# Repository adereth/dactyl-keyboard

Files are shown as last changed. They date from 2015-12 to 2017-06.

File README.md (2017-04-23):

# The Dactyl Keyboard
The Dactyl is a parameterized, split-hand, concave, columnar, ergonomic keyboard.

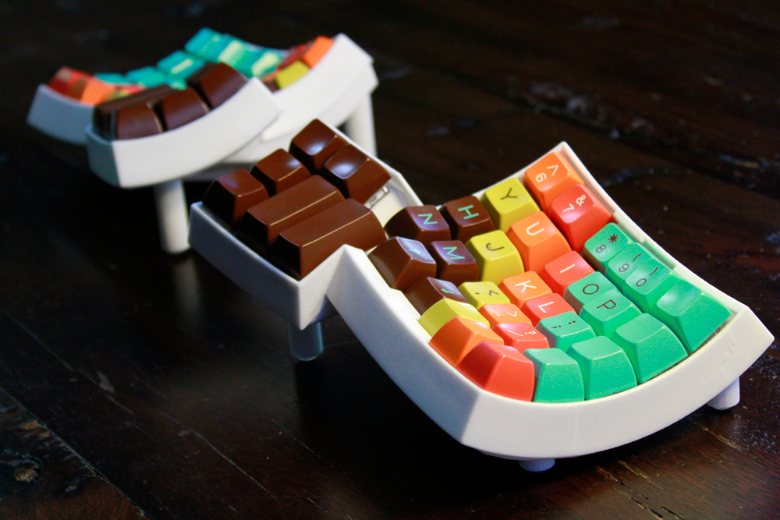
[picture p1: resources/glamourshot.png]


There's a talk about the motivation and design of the Dactyl that helps provide context for this repo:

IMAGE ALT TEXT HERE (https://www.youtube.com/watch?v=uk3A41U0iO4)

## Assembly

### Generating a Design

**Setting up the Clojure environment**
* [Install the Clojure runtime](https://clojure.org)
* [Install the Leiningen project manager](http://leiningen.org/)
* [Install OpenSCAD](http://www.openscad.org/)

**Generating the design**
* Run `lein repl`
* Load the file `(load-file "src/dactyl_keyboard/dactyl.clj")`
* This will regenerate the `things/*.scad` files
* Use OpenSCAD to open a `.scad` file.
* Make changes to design, repeat `load-file`, OpenSCAD will watch for changes and rerender.
* When done, use OpenSCAD to export STL files

**Tips**
* [Some other ways to evaluate the clojure design file](http://stackoverflow.com/a/28213489)
* [Example designing with clojure](http://adereth.github.io/blog/2014/04/09/3d-printing-with-clojure/)

### Printing
Pregenerated STL files are available in the [things/](things/) directory.

### Wiring
Masks for the flexible PCBs I used are available for the [left](resources/pcb-left.svg) and [right](resources/pcb-right.svg) side.

A [very rough guide for the brave is here](guide/README.org#wiring) - It will be improved over time (**TODO**)!

## License

Copyright © 2015 Matthew Adereth

The source code for generating the models (everything excluding the [things/](things/) and [resources/](resources/) directories is distributed under the [GNU AFFERO GENERAL PUBLIC LICENSE Version 3](LICENSE).  The generated models and PCB designs are distributed under the [Creative Commons Attribution-ShareAlike License Version 4.0](LICENSE-models).

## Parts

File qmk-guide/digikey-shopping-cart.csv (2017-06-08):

Index | Quantity | Part Number | Description | Customer Reference | Available Quantity | Backorder Quantity | Unit Price USD | Extended Price USD
1 | 2 | CP-43514-ND | CONN JACK 4COND 3.5MM R/A |  | 2 | 0 | 1.06000 | 2.12
2 | 2 | 2.2KQBK-ND | RES 2.2K OHM 1/4W 5% AXIAL |  | 2 | 0 | 0.10000 | 0.20
3 | 3 | 220QBK-ND | RES 220 OHM 1/4W 5% AXIAL |  | 3 | 0 | 0.10000 | 0.30
4 | 1 | 1528-1993-ND | TEENSY (ATMEGA32U4 USB DEV BOARD |  | 1 | 0 | 19.94000 | 19.94
5 | 100 | 1N4148FS-ND | DIODE GEN PURP 100V 200MA DO35 |  | 100 | 0 | 0.03080 | 3.08
6 | 10 | ED3050-5-ND | CONN IC DIP SOCKET 28POS TIN |  | 10 | 0 | 0.31500 | 3.15
7 | 1 | MCP23018-E/SP-ND | IC I/O EXPANDER I2C 16B 28SDIP |  | 1 | 0 | 1.56000 | 1.56

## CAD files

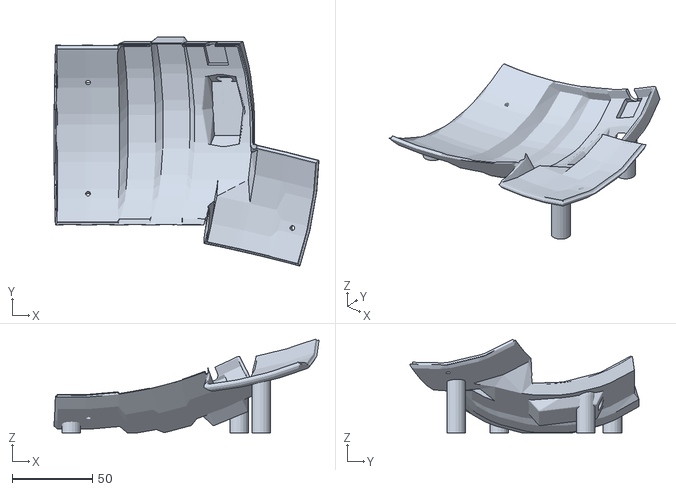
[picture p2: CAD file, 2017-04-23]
things/dactyl-bottom-left-with-teensy.stl
164.7 x 142.2 x 58.3

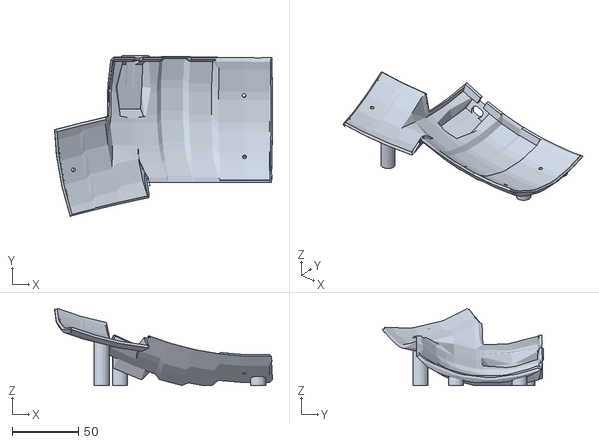
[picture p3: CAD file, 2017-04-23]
things/lightcycle-cherry-bottom-right.stl
164.7 x 121.4 x 58.4

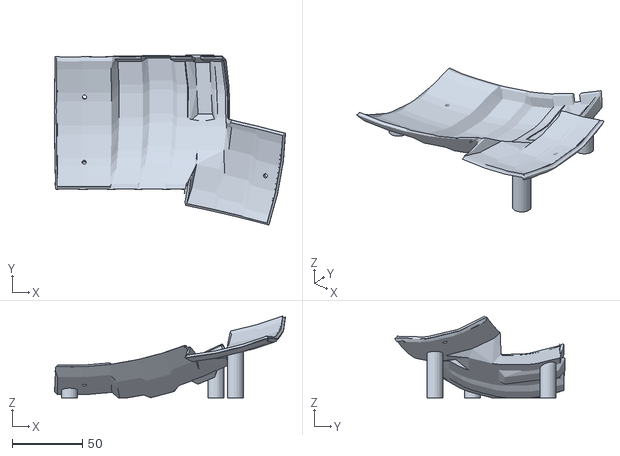
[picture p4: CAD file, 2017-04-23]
things/lightcycle-cherry-bottom-left.stl
164.7 x 121.4 x 58.4

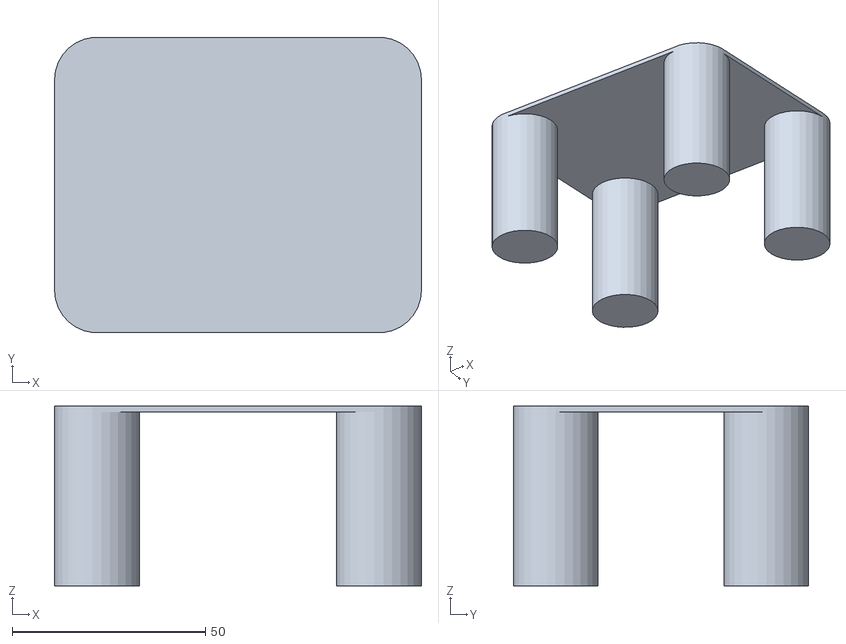
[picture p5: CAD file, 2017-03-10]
things/wrist.stl
95.0 x 76.4 x 46.5

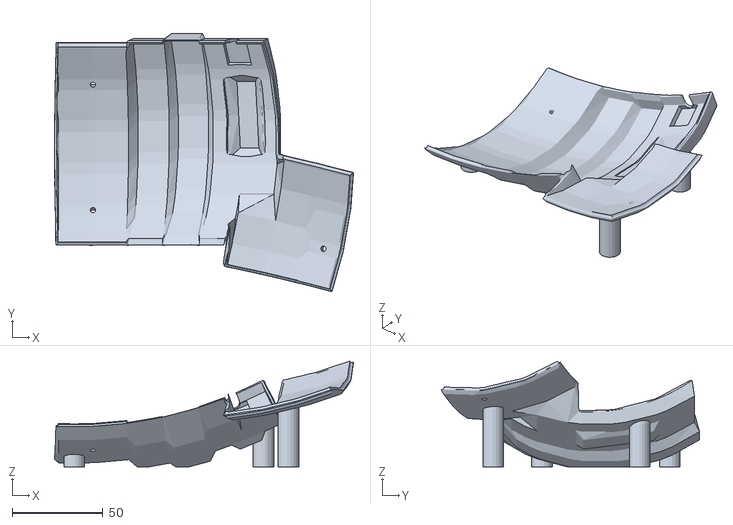
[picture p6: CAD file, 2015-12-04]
things/dactyl-bottom-left.stl
164.7 x 142.2 x 58.3

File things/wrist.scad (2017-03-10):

union () {
  hull () {
    translate ([73/2, 27.25, 45.75]) {
      cylinder (h=1.5, r=11, center=true);
    }
    mirror ([-1, 0, 0]) {
      translate ([73/2, 27.25, 45.75]) {
        cylinder (h=1.5, r=11, center=true);
      }
    }
    mirror ([0, -1, 0]) {
      translate ([73/2, 27.25, 45.75]) {
        cylinder (h=1.5, r=11, center=true);
      }
    }
    mirror ([-1, 0, 0]) {
      mirror ([0, -1, 0]) {
        translate ([73/2, 27.25, 45.75]) {
          cylinder (h=1.5, r=11, center=true);
        }
      }
    }
  }
  hull () {
    translate ([73/2, 27.25, 45.75]) {
      cylinder (h=1.5, r=11, center=true);
    }
    translate ([0, 0, 1/2]) {
      linear_extrude (height=1, twist=0.0, convexity=0, center=true){
        projection (cut = false) {
          translate ([73/2, 27.25, 45.75]) {
            cylinder (h=1.5, r=11, center=true);
          }
        }
      }
    }
  }
  hull () {
    mirror ([-1, 0, 0]) {
      translate ([73/2, 27.25, 45.75]) {
        cylinder (h=1.5, r=11, center=true);
      }
    }
    translate ([0, 0, 1/2]) {
      linear_extrude (height=1, twist=0.0, convexity=0, center=true){
        projection (cut = false) {
          mirror ([-1, 0, 0]) {
            translate ([73/2, 27.25, 45.75]) {
              cylinder (h=1.5, r=11, center=true);
            }
          }
        }
      }
    }
  }
  hull () {
    mirror ([0, -1, 0]) {
      translate ([73/2, 27.25, 45.75]) {
        cylinder (h=1.5, r=11, center=true);
      }
    }
    translate ([0, 0, 1/2]) {
      linear_extrude (height=1, twist=0.0, convexity=0, center=true){
        projection (cut = false) {
          mirror ([0, -1, 0]) {
            translate ([73/2, 27.25, 45.75]) {
              cylinder (h=1.5, r=11, center=true);
            }
          }
        }
      }
    }
  }
  hull () {
    mirror ([-1, 0, 0]) {
      mirror ([0, -1, 0]) {
        translate ([73/2, 27.25, 45.75]) {
          cylinder (h=1.5, r=11, center=true);
        }
      }
    }
    translate ([0, 0, 1/2]) {
      linear_extrude (height=1, twist=0.0, convexity=0, center=true){
        projection (cut = false) {
          mirror ([-1, 0, 0]) {
            mirror ([0, -1, 0]) {
              translate ([73/2, 27.25, 45.75]) {
                cylinder (h=1.5, r=11, center=true);
              }
            }
          }
        }
      }
    }
  }
}

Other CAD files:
things/dactyl-bottom-right.stl

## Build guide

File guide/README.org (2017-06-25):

* Preparation and Cost
  Get all the parts / raw material:
  - For the 3D printing there are two options:
    1. Filament, which is the basis for 3D printing. Luckily I could print at my work-place
       which reduced the cost from 210€ to 70€. The kind of filament you need depends on the 3D
       printer you have available.
    2. Buy the printout of adareth's model at shapeways for 210€ over here
       http://www.shapeways.com/designer/adereth/creations
  - Decide on the switches
    - If you are going to invest a whole lot of time and money for a custom keyboard instead of
      buying one for 10€ I'd recommend to use your favorite switch-type. To make a
      well-informed decision I bought a switch-tester for this from massdrop and decided on
      Cherry MX Whites. https://www.massdrop.com/buy/varmilo-switch-tester-with-anodized-case
    - I ordered 70 Cherry MX Whites from here:
      https://mechanicalkeyboards.com/shop/index.php?l=product_detail&p=847
  - Decide on the key caps
    - On the glamour shot you can see the 1976 keycap set; it used to be sold over here:
      http://pimpmykeyboard.com/sa-1976-keycap-set/ but the link is dead right now. You could
      try this link: https://www.massdrop.com/buy/nineteenseventysix-sa-keycap-set but it is a
      massdrop which is way different from usual online-stores. If you find a site that sells
      these, make sure you get the right amount and type of keys according to the layout.
    - I got the "TKL Base Set + TKL Modifier" from over here:
      http://pimpmykeyboard.com/dsa-pbt-abs-blank-keycap-sets/ but I'm still two long keys
      short, I will have to order those specifically and I have a bunch of keys I don't use
      left-over.
  - The USB-Cable that connects the keyboard to your computer
    - It's an USB 2.0 to USB Mini-B cable, make sure you get one that is 2 meters long, it
      really makes handling the keyboard so much more comfortable
    - https://www.amazon.de/gp/product/B00NH11N5A/
  - The main controller (right half)
    - A Teensy 2.0, I got that one from here: https://www.pjrc.com/store/teensy.html
  - The chip, connectors and cable to give life to the left half
    - TRRS cable and jacks
      - Got my TRRS cable from here: http://www.digikey.de/product-search/de?keywords=839-1257-ND
      - Got my TRRS jacks from here: http://www.digikey.de/product-search/de?keywords=CP-43514-ND
    - MCP23018 16 bit IO Expander
      - Got mine from here: http://www.digikey.de/product-search/de?keywords=MCP23018-E%2FSP-ND

  What I spend on my keyboard (should give you a rough estimate for your build):
  | item                              | cost |
  |-----------------------------------+------|
  | filament                          |   70 |
  | switch-tester                     |   30 |
  | key-caps                          |   70 |
  | teensy 2.0                        |   30 |
  | switches                          |   60 |
  | usb cable                         |   10 |
  | IO Expander, TRRS jacks and cable |   30 |
  |-----------------------------------+------|
  | overall cost                      |  300 |
  #+TBLFM: @9$2=vsum(@2$2..@8$2)

  My choices / advantages:
  - Using the soldering iron at the uni-workshop for free
  - 76 Diodes for free
  - Soldering wire and copper for free
  - All the resistors used for free (5 resistors are used)
  - Several files for working out the rough edges of the 3D-printout

  Depending on what you have available you might spend more or less money than me; however, 300€
  is a good rough estimate.

  After all the parts have arrived it is safe to move on to the next section.

* Wiring
  It is assumed that you have printed the casing successfully.

  1) Plug the switches into the casing. No glue is needed; the casing provides the perfect fit.
  2) Put the keycaps on the switches
     - Note that in the pictures here some of the long keys on the thumb-part are too short;
       that's why it doesn't look symmetrical

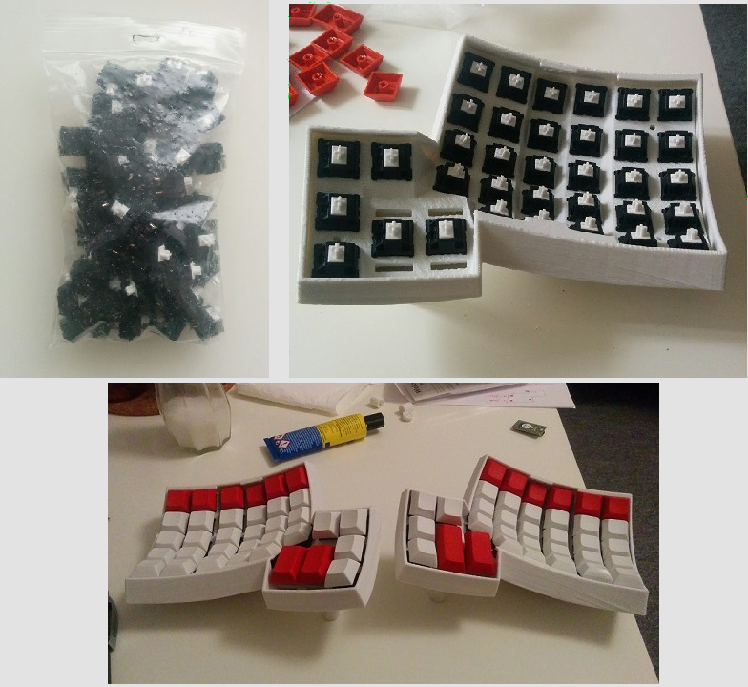
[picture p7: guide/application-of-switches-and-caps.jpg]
  

  Now going further on in the guide there are two options
  1. The first option is to print flexible PCBs. The advantage is that you save a lot of wiring
     business, everything looks rather clean and you don't have to worry about your cables being too
     thick such that the casing doesn't close. However, if you don't have the means to print out such
     PCBs there is the second option, wiring everything by hand.
     - The guide for this PCB-option is very rough indeed and it doesn't include the firmware
       used. Wiring and firmware play extremely close together--wiring before knowing your
       firmware is like buying a shoe without measuring your feet before. For this option,
       information about the exact firmware is not published, this in addition to the fact that
       the pictures in this rough guide are incomplete makes this option extremely
       beginner-unfriendly. Going in blind-sided like this may lead to one of these things:
       1. reprogramming huge parts of the firmware to match your wiring, which comes with a ton of
          debugging.
       2. rewiring to adapt to what the firmware expects, which may easily double your work here.
     - [[Route 1: Dactyl Flexible PCB Rough Guide]]
  2. The second option is to hand-wire everything. For people like me, who had never soldered before,
     this was great pain and pleasure.
     - Here too firmware and wiring go hand in hand, you pretty much have to have a detailed look
       at the firmware you are using before wiring anything. I provide my modification of the
       "ergodox-firmware" over here: https://github.com/BubblesToTheLimit/ergodox-firmware
       - TODO: Make a successfull pull-request, such that it is available in the official
         ergodox-firmware
     - Some of the steps of this guide may not be described in much detail, but in contrast to
       option one there is a whole lot more information.
     - [[Route 2: Dactyl Hand-Wiring Guide]]

** Route 1: Dactyl Flexible PCB Rough Guide
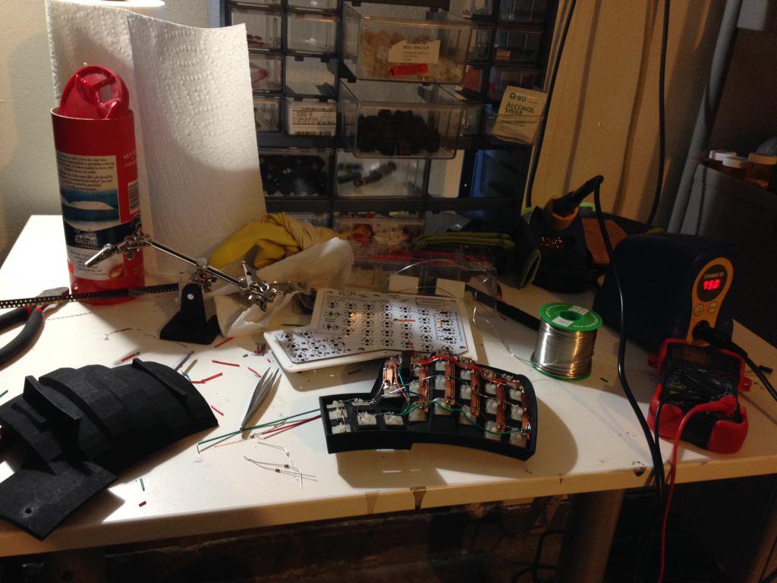
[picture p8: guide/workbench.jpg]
   

   For now, take a look at the images and try to figure things out; I know that's not great (it's
   better than nothing!)

*** Making the PCB
    Get two sheets of 6in square Pyralux™. Use the Toner Transfer method to etch the Pyralux sheets as
    you would a usual PCB

    #+BEGIN_QUOTE
    NOTE: If you only have an Inkjet make photocopies of the print out. Voilà, Toner based copies!
    #+END_QUOTE

    [[http://www.instructables.com/id/Toner-transfer-no-soak-high-quality-double-sided/][Here's a handy toner transfer guide ...]]

    Print these PCB designs out...

    Left hand:

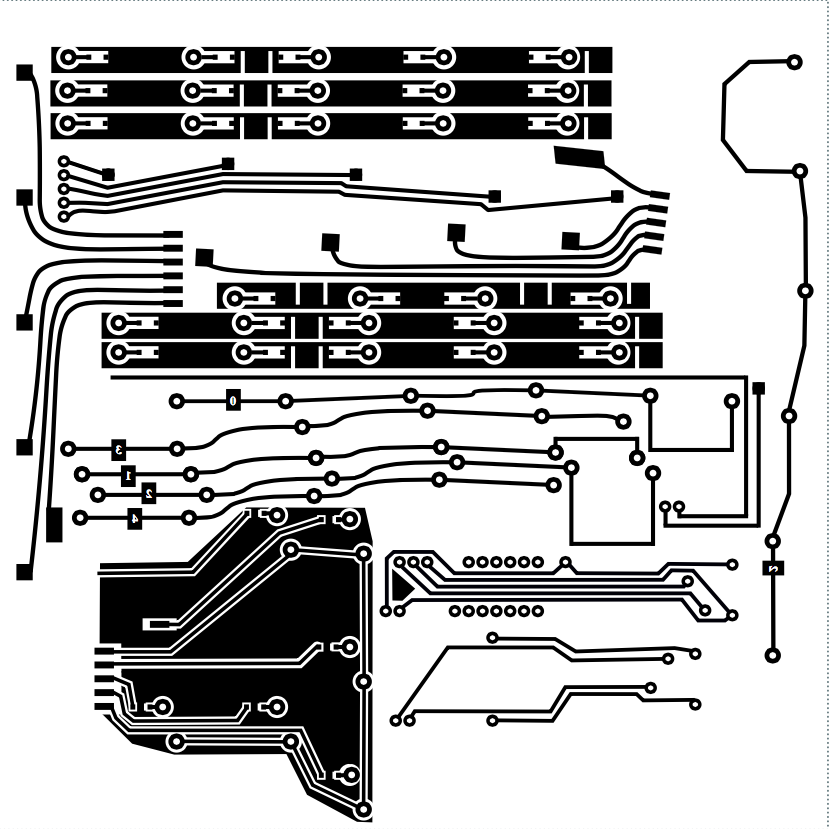
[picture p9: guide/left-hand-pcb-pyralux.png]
    

    Right hand:

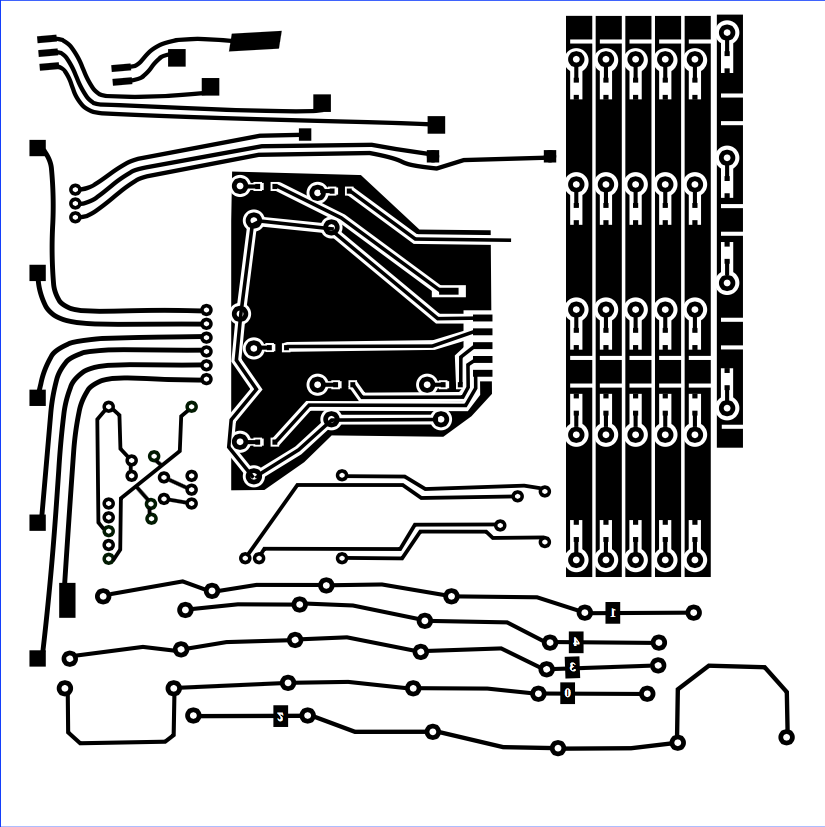
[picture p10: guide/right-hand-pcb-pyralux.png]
    

    When you're done etching, you'll need to carefully cut the pcb into pieces... See the images
    below.

*** Applying the PCB to the electronical parts
    The thumb cluster pcb for the left hand:

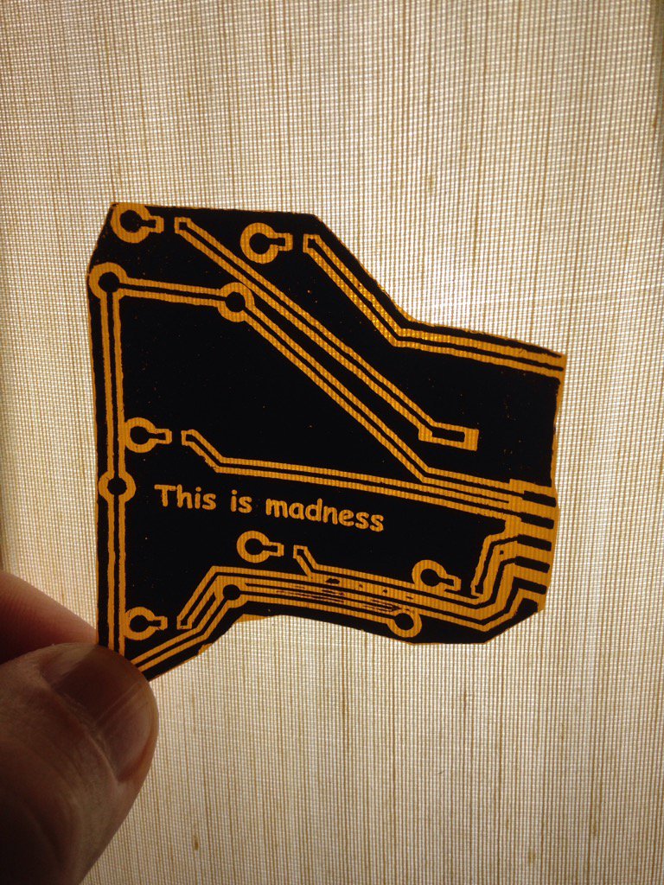
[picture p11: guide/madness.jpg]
    

    Solder the MCP like so:

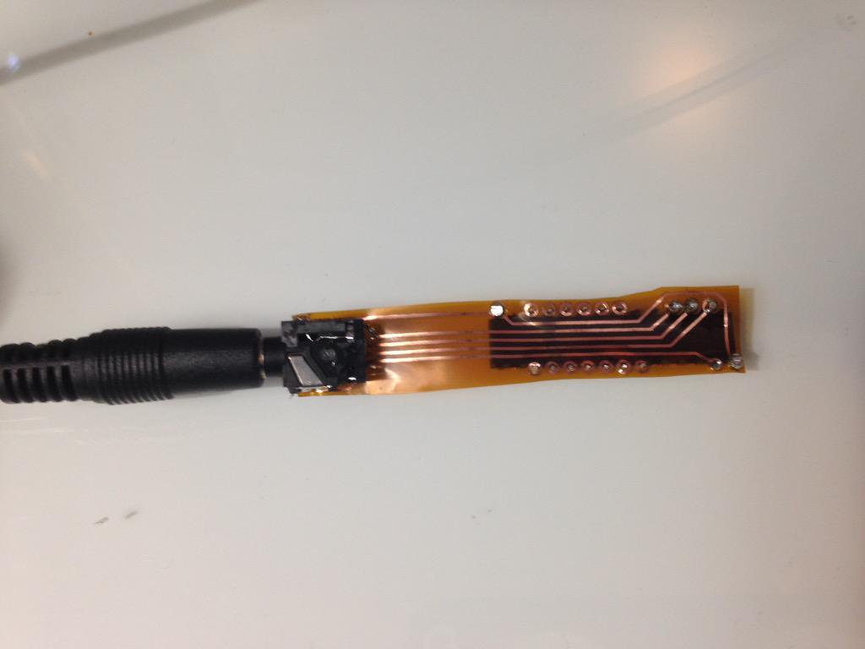
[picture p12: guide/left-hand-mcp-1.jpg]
    
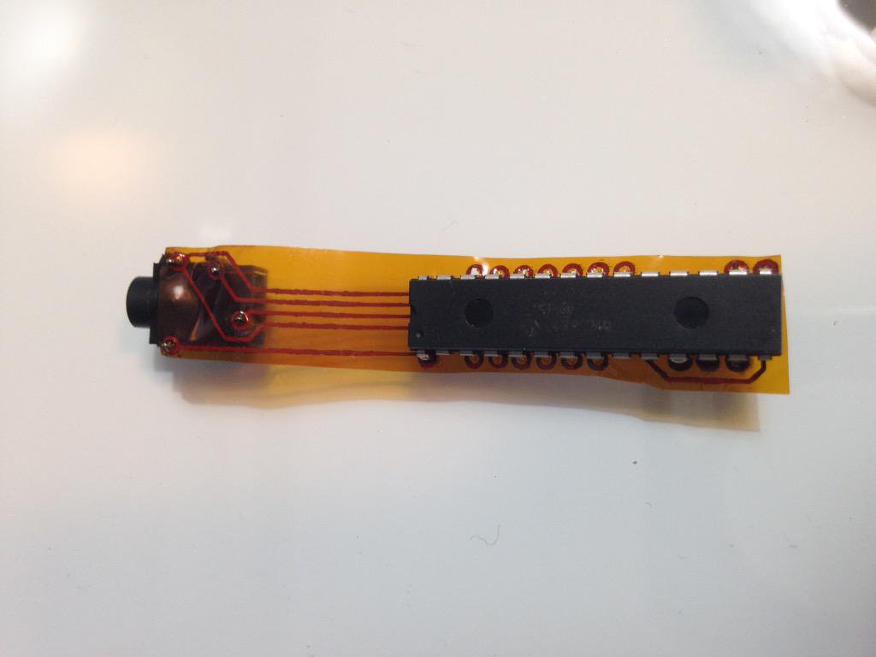
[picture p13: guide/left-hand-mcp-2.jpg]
    

    Solder the Teensy 2.0 like so:

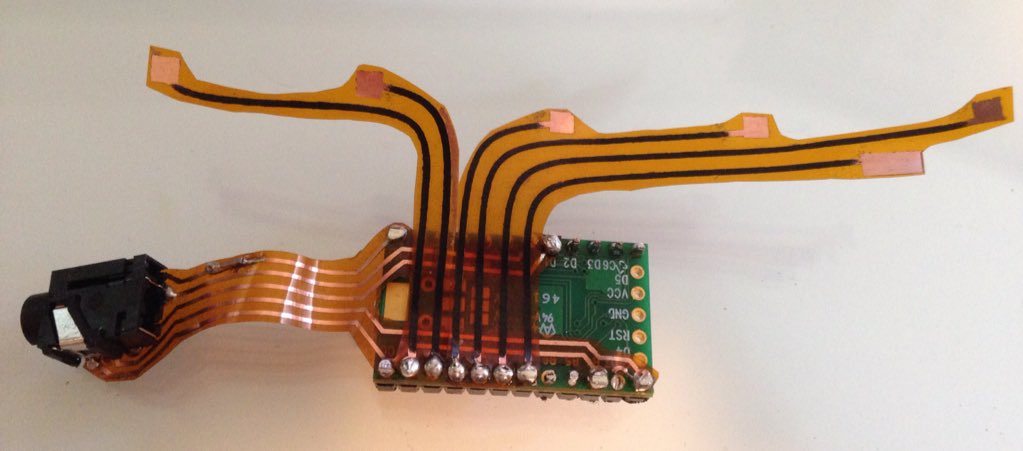
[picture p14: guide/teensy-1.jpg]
    

    The two 2.2kΩ (Red Red Red Gold) pull-up resistors ensure a clear signal between the USB controller and the I/O expander.
    [[https://learn.sparkfun.com/tutorials/pull-up-resistors][Read more about pull-up resistors here]].

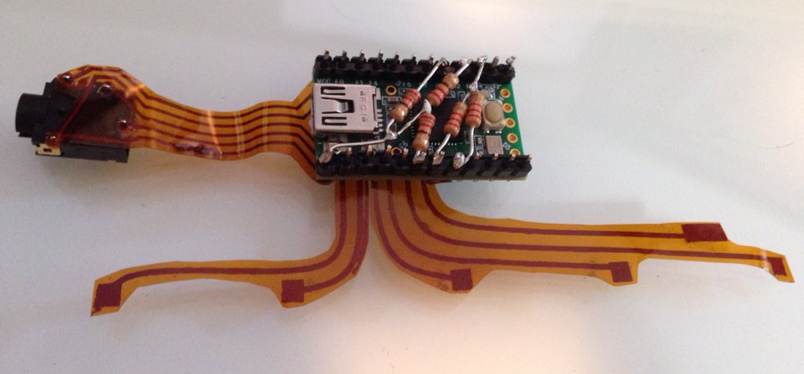
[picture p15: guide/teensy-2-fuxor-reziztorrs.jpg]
    

    Each hand of the keyboard will wire up like so:

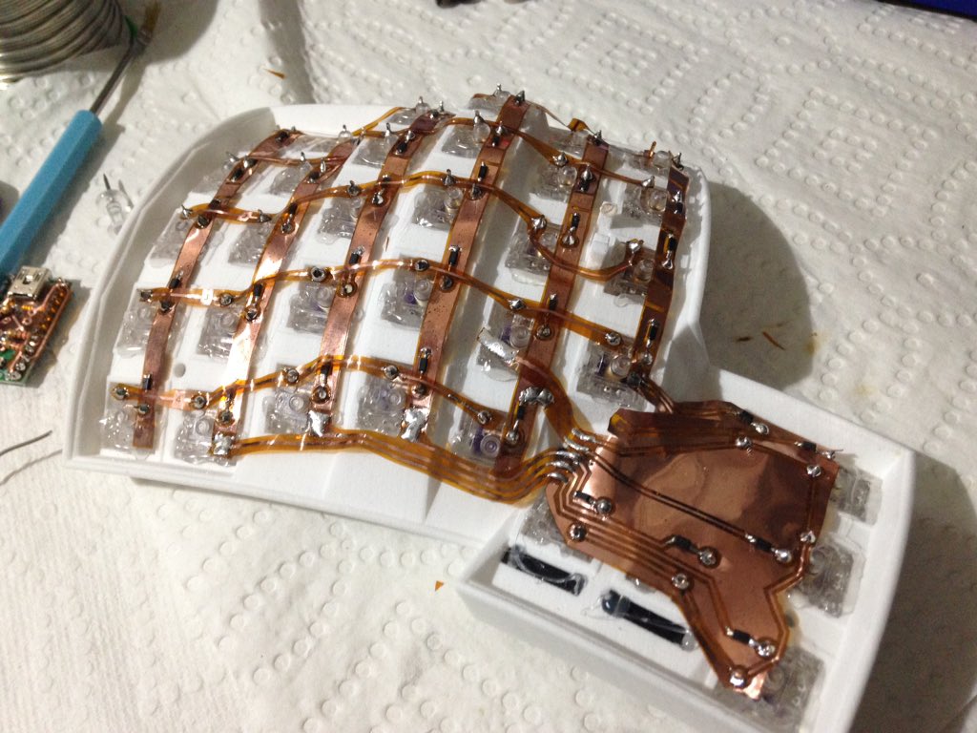
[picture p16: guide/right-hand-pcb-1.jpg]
    

    Teensy goes here... note the rows soldered to the teensy via the Pyralux:

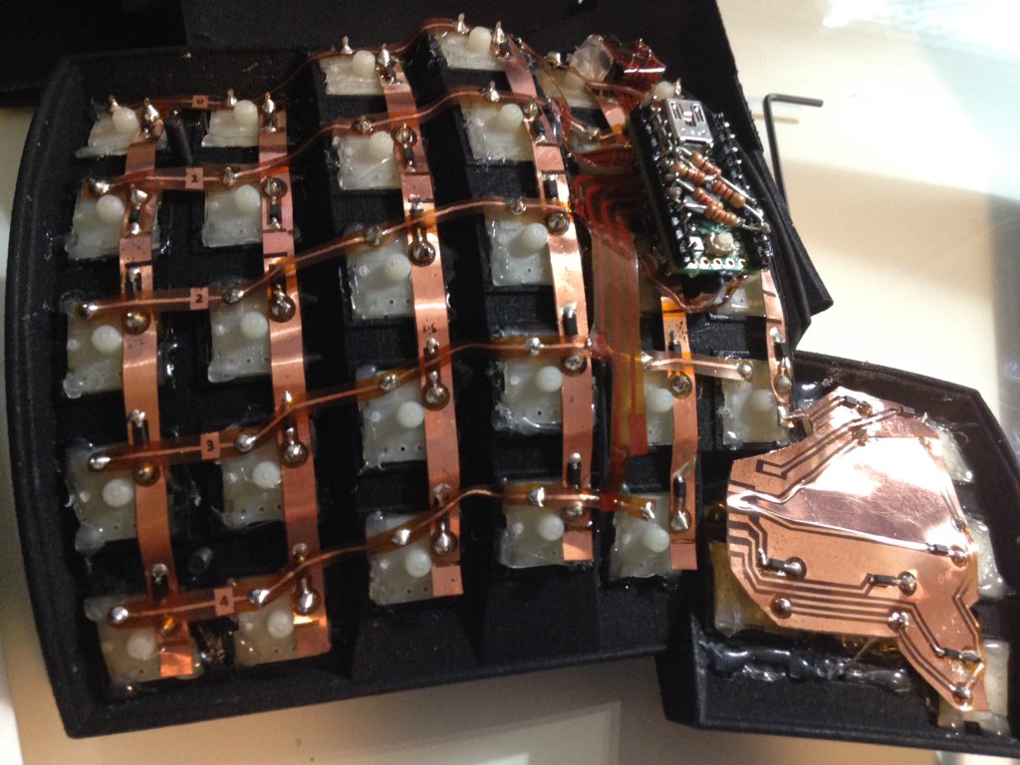
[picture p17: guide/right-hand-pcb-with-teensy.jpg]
    

    Here the left hand:

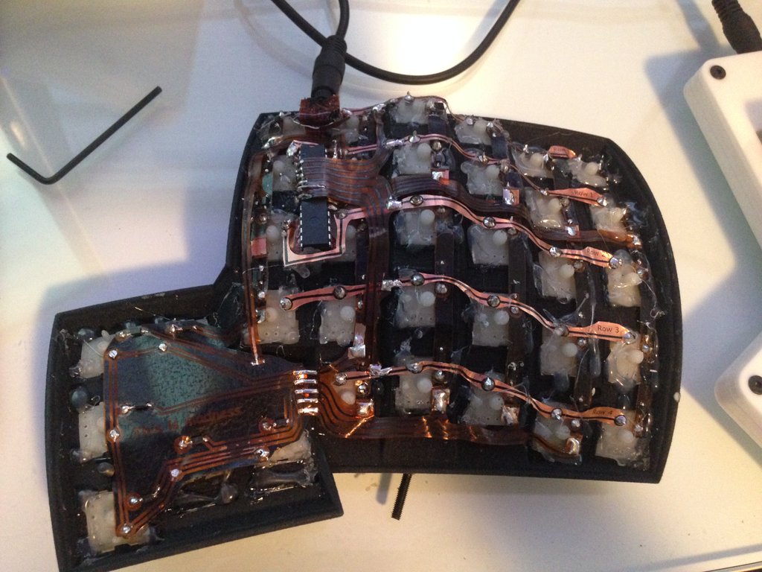
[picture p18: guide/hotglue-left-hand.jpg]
    

** Route 2: Dactyl Hand-Wiring Guide
*** Step 1: Creating the rows
    Using the copper wire you solder each row together, notice how the thumb-part gets its own
    row. If you take a close look you can see how I did do a messy job soldering, I had to redo
    some of the parts because they weren't soldered properly. Do this for both sides. It doesn't
    matter which of the two available pins of each switch you chose for the row, but for it to
    look clean you should decide for either one of them.

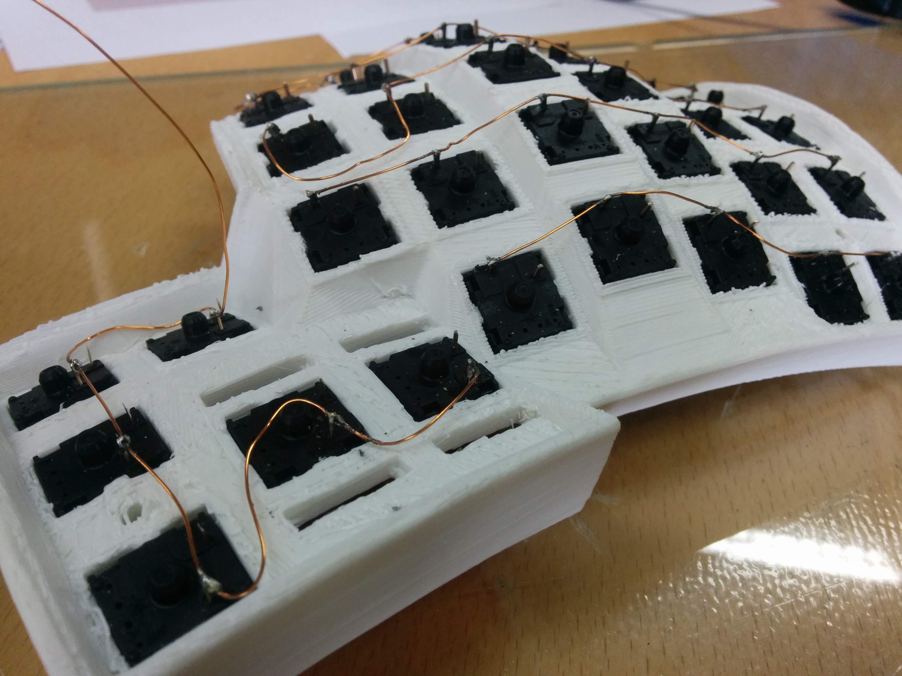
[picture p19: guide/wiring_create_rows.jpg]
    

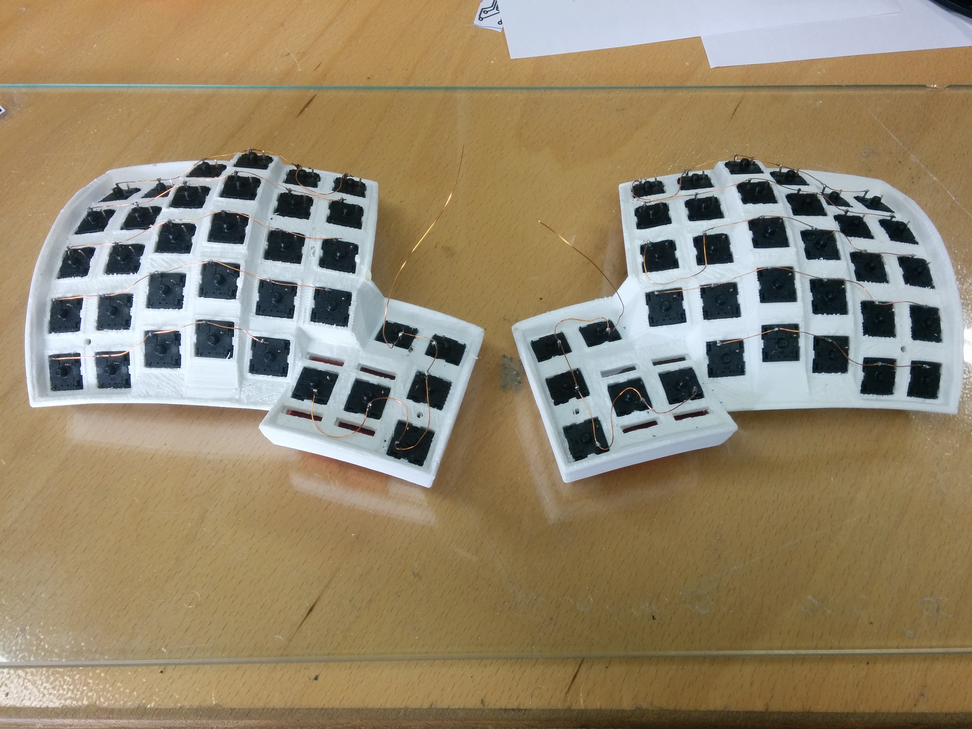
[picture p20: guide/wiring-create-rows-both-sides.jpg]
    

    You might want to go ahead and test each one of the 70 switches with a multimeter.

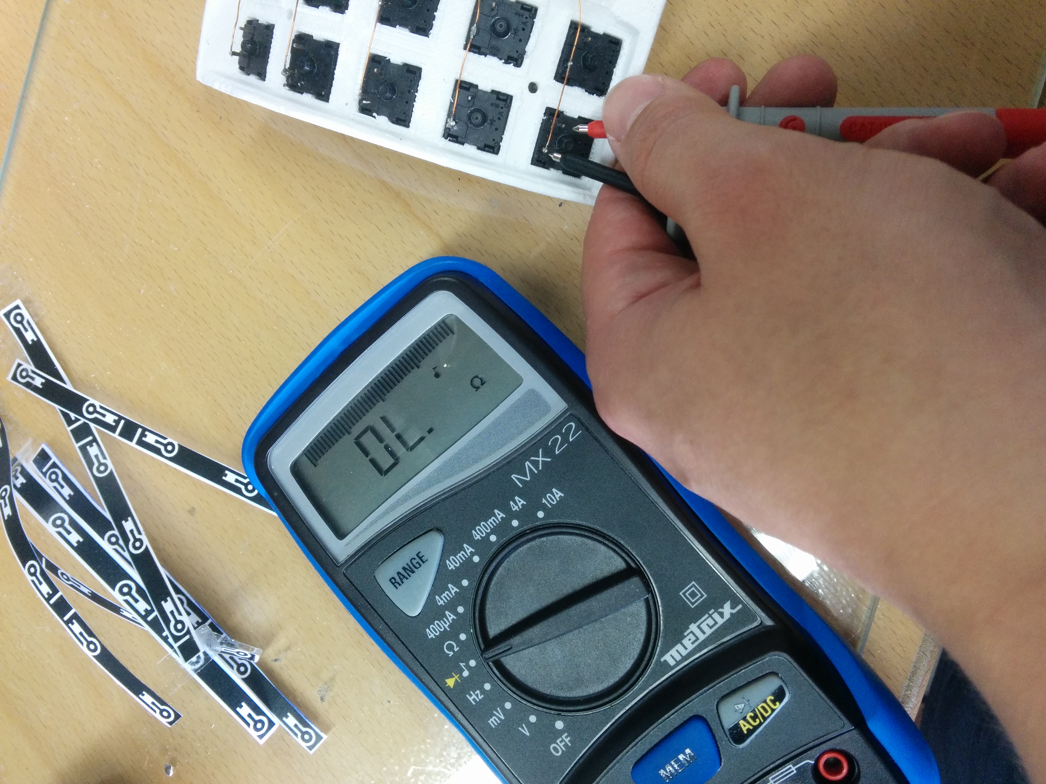
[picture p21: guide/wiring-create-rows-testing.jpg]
    

*** Step 2: Create the columns
    The next step is to create the columns by soldering the diodes. There are two options for
    soldering the diodes, all heading towards the switch or all heading away from the
    switch. These two ways are called "row-driven" or "column-driven" and here again it is
    cruciual for the firmware and the actual wiring to be on the same page.

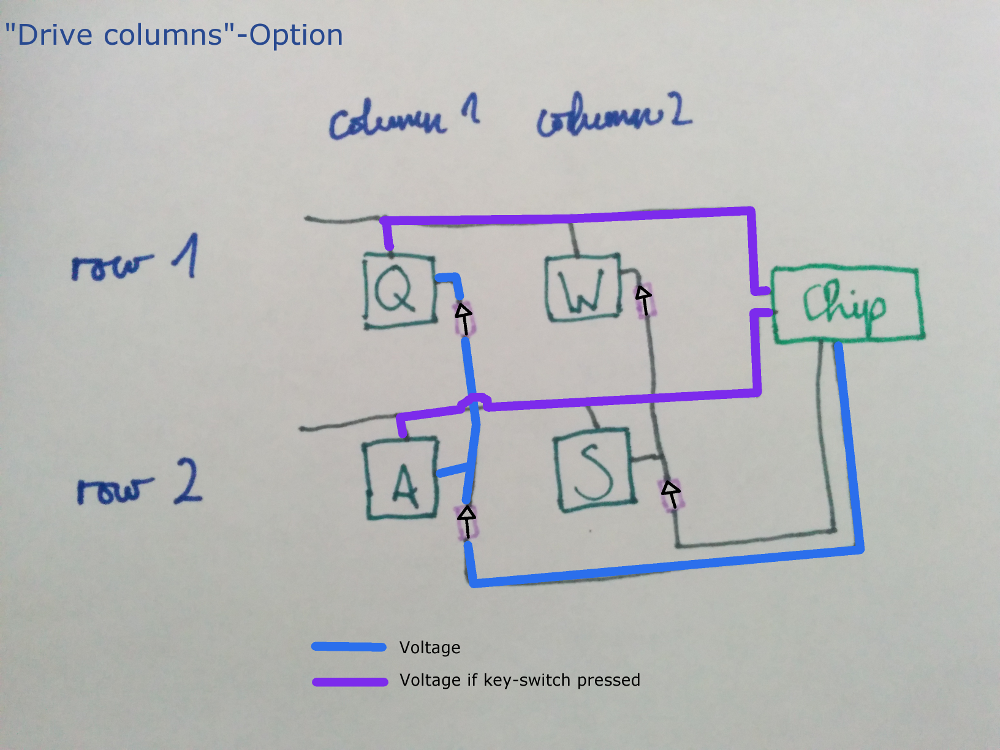
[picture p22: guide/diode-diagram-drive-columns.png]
    

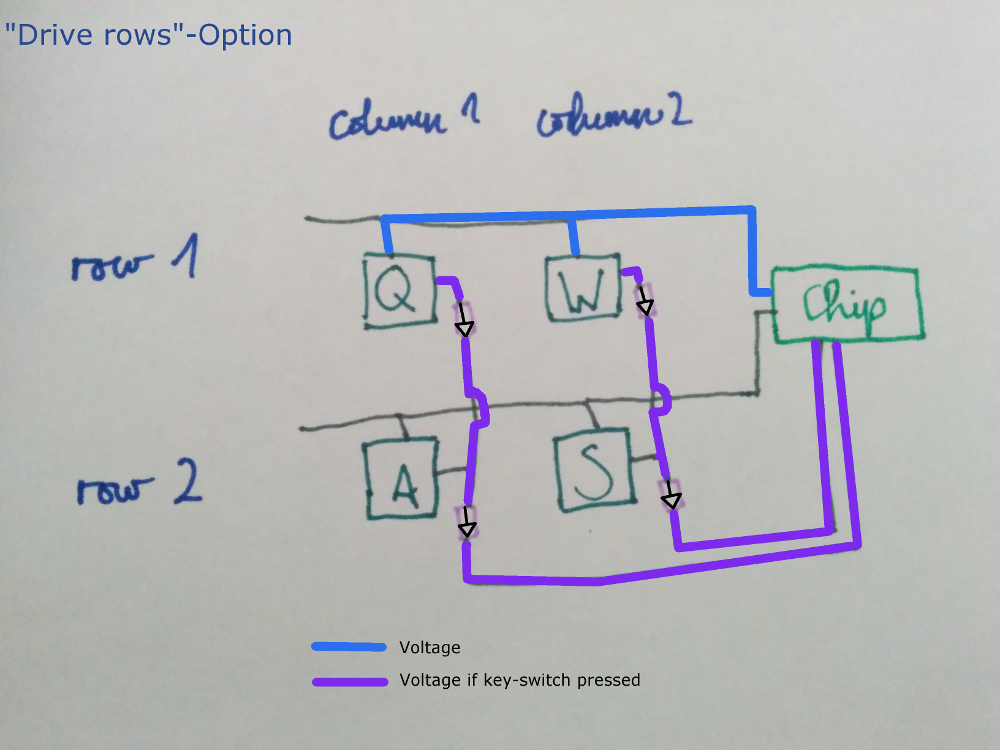
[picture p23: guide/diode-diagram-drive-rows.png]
    

    If you want to try and use the "tmk_keyboard" firmware which seems to be also interesting you
    want to wire the diodes in the according way (check whether the tmk_keyboard firmware expects
    a row-driven or a column-driven setup).

    As you can see in these following pictures, I went for the "row-driven" setup (visible by the
    direction of the diodes, the black line being towards the key-switches). This first picture
    doesn't show how the 6 thumb-keys are actually individually connected to the 6 main columns,
    but note the small black line on each diode.

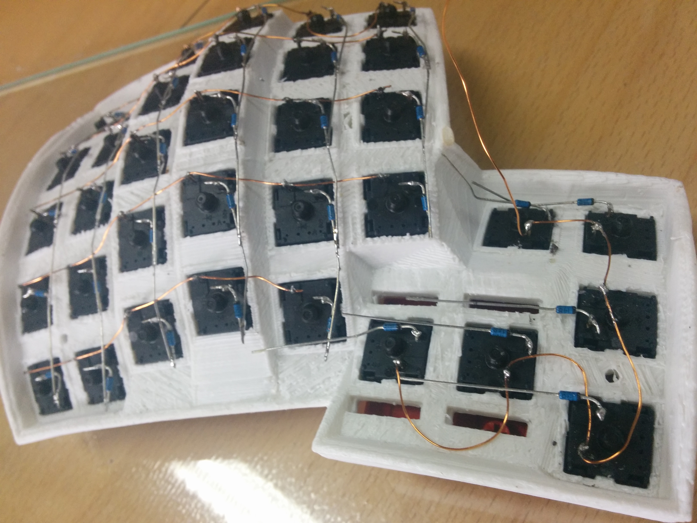
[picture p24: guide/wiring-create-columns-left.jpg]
    

    This second picture shows how the 6 thumb-keys are actually connected to the 6 main columns.

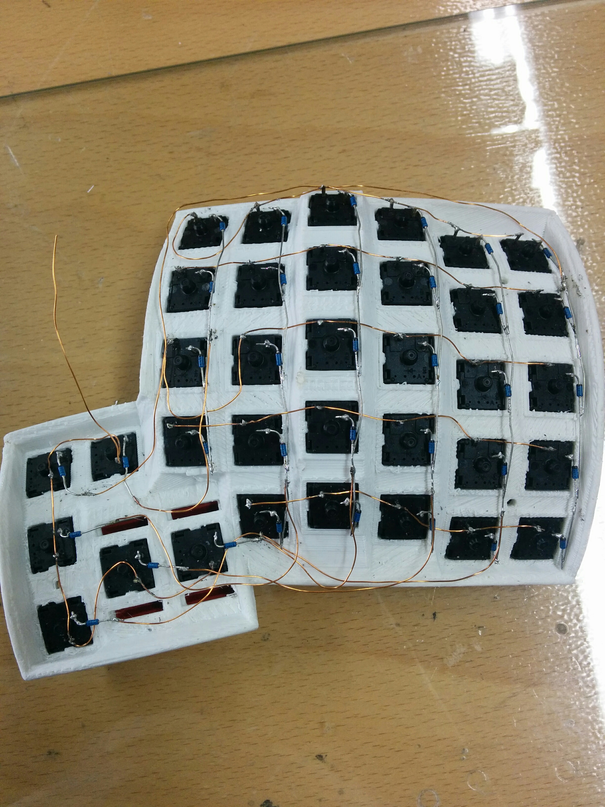
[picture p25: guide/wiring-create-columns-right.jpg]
    

    How thumb-keys are wired again depends on the firmware. The following picture shows the wiring
    of the thumb keys more clearly and also the part in the code that reflects this wiring
    (ergodox-firmware/src/keyboard/dactyl/matrix.h).

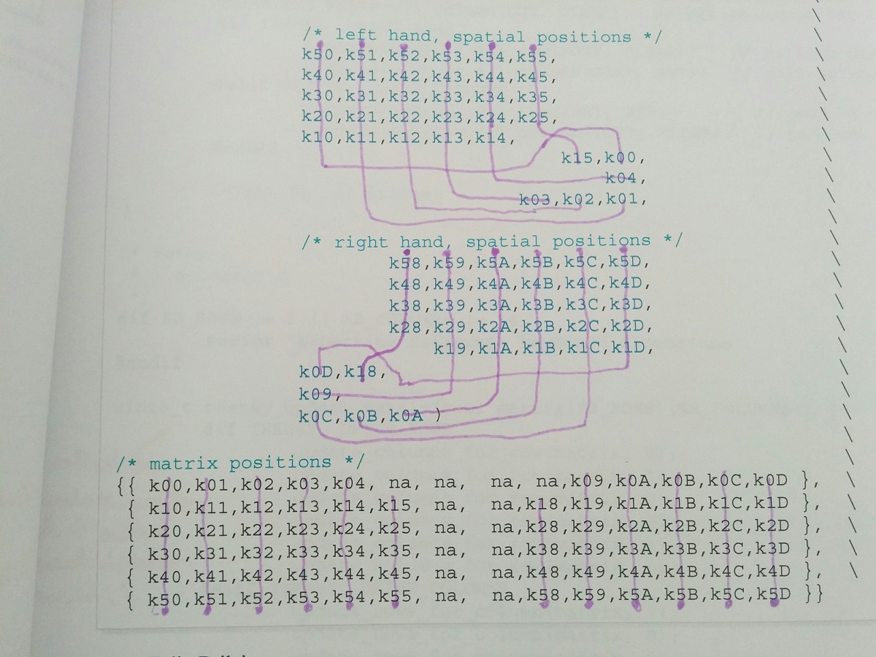
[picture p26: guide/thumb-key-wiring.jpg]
    

*** Step 3: Put the Teensy and the MCP in place
    This next step is to wire the Teensy 2.0 and the MCP 23018 in place.
    Everything necessary for that really is the following circuit diagram.

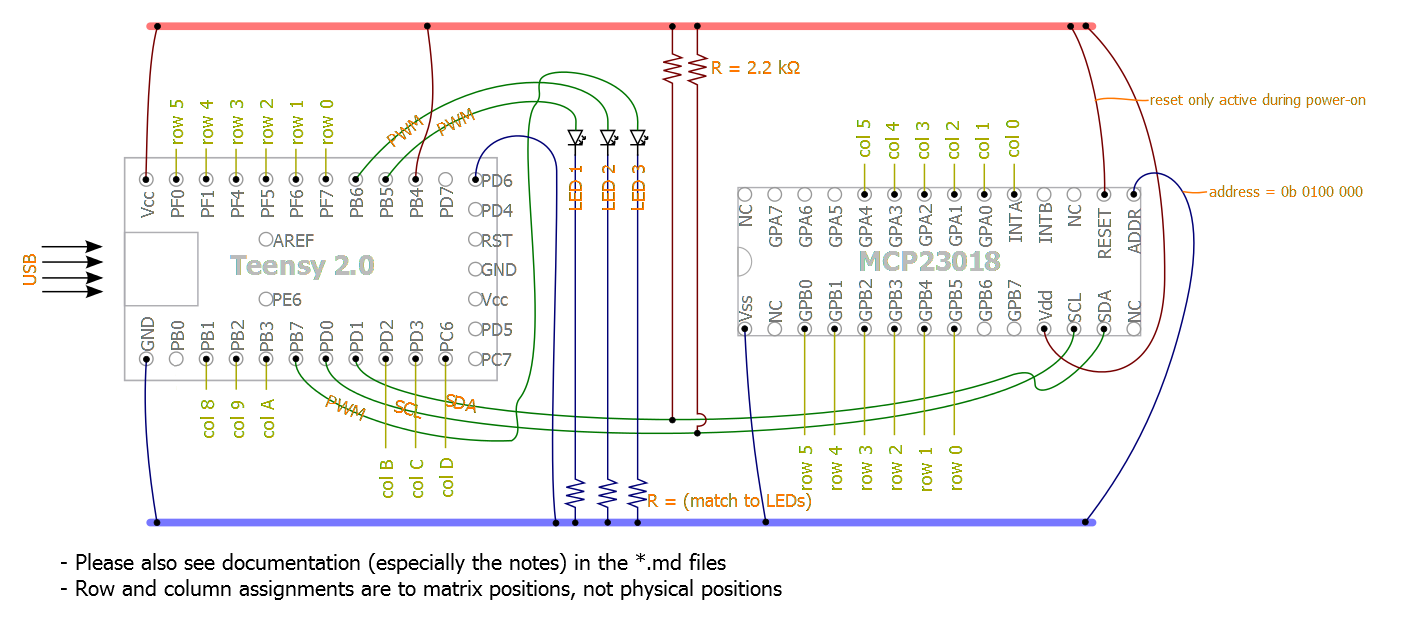
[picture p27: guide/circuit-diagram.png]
    

    Things to note here:
    - The columns for the MCP go from 0 to 6, the columns for the Teensy go from 7 to D (counting
      in hexadecimal) which makes great sense, since the MCP is to the left of the Teensy and we
      read from left to right.
    - When debugging this and using the ergodox-firmware, both sides have to be wired completely
      and actually with the TRRS connected. Don't expect the keyboard to work before that. The
      reason is that the ergodox-firmware stops completely if either the Teensy or the MCP weren't
      initiated properly.
    - The LEDs are handy for debugging; definitely go ahead and connect those. When the keyboard
      starts successfully two of the LEDs light up shortly.
    - From the Teensy over to the MCP go exactly 4 connections. The blue, the red and the two green
      ones. This is done using the TRRS jacks and cable.
    - Yes, the connection from B4 to VCC doesn't seem to make any sense, but the B4 port actually
      gets used directly in the ergodox-firmware, so just connect those connections that make no
      sense on first sight and either don't question it or find out why this is necessary by going
      through the firmware in great detail.

    This is how the trrs jacks are wired:

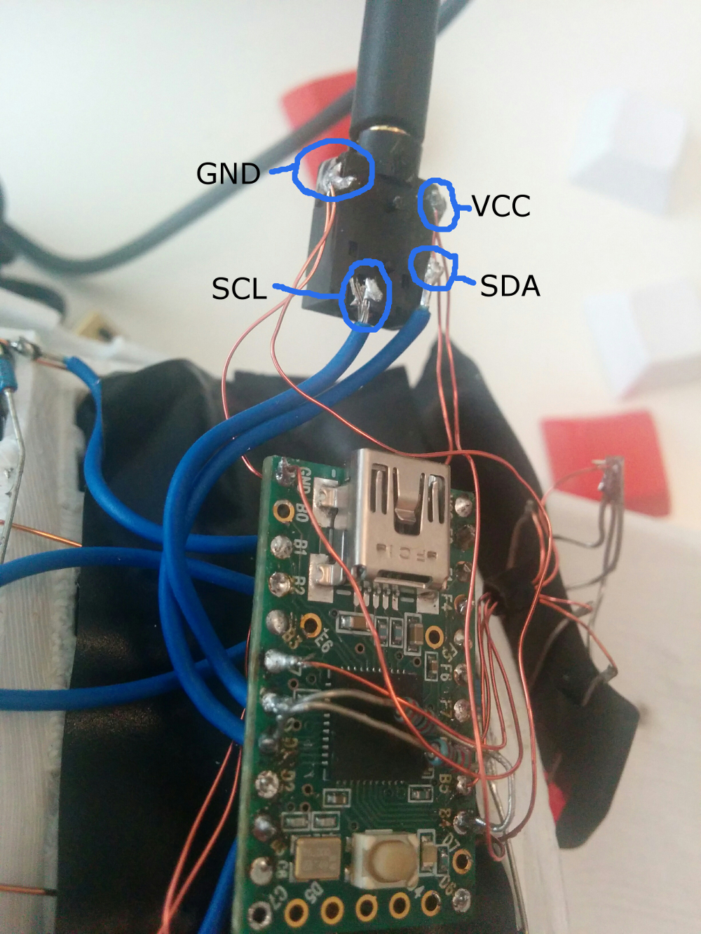
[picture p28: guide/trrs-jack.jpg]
    

    After you are done you might have the following result:

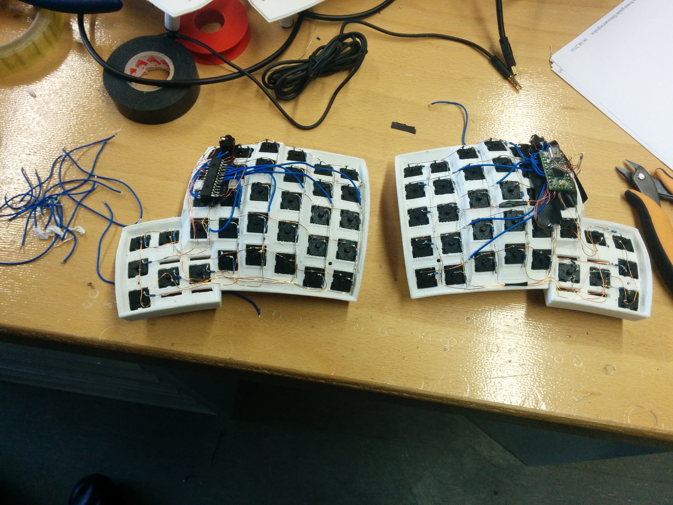
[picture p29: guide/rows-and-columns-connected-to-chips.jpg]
    

    Good luck!

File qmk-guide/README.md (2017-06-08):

# The EZ Way to QMK

Do you love your Kinesis Advantage, but also love your Ergodox-EZ? Now you can
have the best of both worlds with your very own QMK running Dactyl! Feels like a
Kinesis, works like an Ergodox-EZ.

I found this [Massdrop guide](massdrop-ergodox-build-guide.pdf) that shipped with their original
Ergodox to be very helpful.

## Shopping List

### Things you'll have to find yourself:

* Case
* 70x Cherry MX compatible Switches
* 6x Cherry ML switches (optional)

### Things you can order from Digikey

#### An aside on LEDs

Before you place this order, you'll need to figure out what color you want your
LEDs to be, or if you even want LEDs at all.

I had a terrible time figuring out how to figure out which resistor to use with
each LED. All I can attest to is that
[These Orange LEDs](http://www.maxkeyboard.com/max-keyboard-orange-3mm-flangeless-replacement-led-for-backlit-mechanical-keyboard-10-pcs.html)
work with
[These 220Ω resistors](http://www.digikey.com/scripts/DkSearch/dksus.dll?Detail&itemSeq=229354283&uq=636318134508631803)
or at least have yet to fail in my Dactyl.

I was hoping that I could find these LEDs on Digikey for you, but they don't
have ones with the exact specs and I don't know if that breaks the compatibility
with the resistors I found.

Here's
[the evil mad scientist's guide](http://www.evilmadscientist.com/2012/resistors-for-leds/)
to choosing resistors for LEDs, but every time I did the math, it didn't work
out.

Seriously, find someone who knows more about this if you're making decisions
here. You're probably already more qualified than me, so open a PR and fix this
session.

* 70x [1N4148 Diodes](http://www.digikey.com/scripts/DkSearch/dksus.dll?Detail&itemSeq=229354375&uq=636318149504319926)
* 2x [2.2kΩ Pull up Resistors](https://www.digikey.com/product-detail/en/CFR-25JB-52-2K2/2.2KQBK-ND/666)
* 2x [TRRS Jacks](http://www.digikey.com/scripts/DkSearch/dksus.dll?Detail&itemSeq=229354247&uq=636318148338283334)
* 1 [Teensy 2.0](https://www.digikey.com/product-detail/en/adafruit-industries-llc/199/1528-1993-ND/6827126)
* 1 [MCP23018 I/O Expander](https://www.digikey.com/product-detail/en/microchip-technology/MCP23018-E-SP/MCP23018-E-SP-ND/1999505)
* [28 Pin IC Socket](http://www.digikey.com/scripts/DkSearch/dksus.dll?Detail&itemSeq=229356912&uq=636318143621851738)

If you want everything in this list from [Digikey](https://www.digikey.com), you
can upload [this cart](digikey-shopping-cart.csv).

### Things From Amazon

* 1x [MiniUSB Extender Cable](https://www.amazon.com/gp/product/B00B5HSA3Q)
* Solder/Electrical Tape/Twosided tape
* [30AWG wrapping wire](https://www.amazon.com/gp/product/B00GWFECWO)
* TRRS Cable [this one](https://www.amazon.com/Coiled-3-5mm-Jack-Audio-Cable/dp/B019TRW4HQ)
  worked for me, but it's a matter of taste and how much distance you need.

## Wiring up the Matrix

The firmware you choose will determine the wiring of the keyboard. Since the
Ergodox-EZ isn't going anywhere **AND** has first class support in QMK by its
creator, it makes pretty good sense to wire it up the same way.

Here's what the matrix code for the Ergodox-EZ in QMK looks like:

```c
// matrix positions
{   // MCP23018
 { k00, k10, k20,   k30, k40,   KC_NO },                     \
 { k01, k11, k21,   k31, k41,   k51   },                     \
 { k02, k12, k22,   k32, k42,   k52   },                     \
 { k03, k13, k23,   k33, k43,   k53   },                     \
 { k04, k14, k24,   k34, k44,   k54   },                     \
 { k05, k15, k25,   k35, KC_NO, k55   },                     \
 { k06, k16, KC_NO, k36, KC_NO, k56   },                     \
    // Teensy
 { k07, k17, KC_NO, k37, KC_NO, k57   },                     \
 { k08, k18, k28,   k38, KC_NO, k58   },                     \
 { k09, k19, k29,   k39, k49,   k59   },                     \
 { k0A, k1A, k2A,   k3A, k4A,   k5A   },                     \
 { k0B, k1B, k2B,   k3B, k4B,   k5B   },                     \
 { k0C, k1C, k2C,   k3C, k4C,   k5C   },                     \
 { k0D, k1D, k2D,   k3D, k4D,   KC_NO }                      \
}
```

This is a software mapping of 14 rows, even though the physical layout will wind
up with 14 columns. Physically, it looks like this:

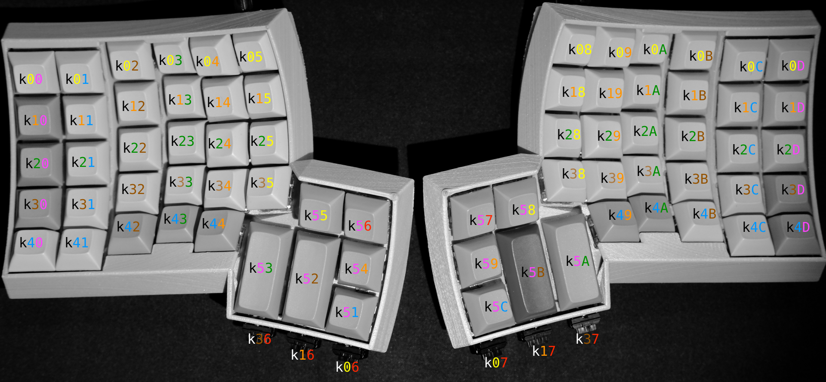
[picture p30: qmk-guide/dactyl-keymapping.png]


Look at those colors, they'll be consistent throughout this documentation,
including the physical wire we wire it up with.

### Rows

You don't have to decide how to connect the rows to the Teensy or MCP yet. Just
worry about getting the matrix right.

Wiring rows 0-4 is easy. With the 30AWG wire, I had to cut individual wire
segments from switch to switch. The thumb clusters are Row 5 on each side, so
the same approach will work, it just doesn't look like a row.

Row 5 is the thumb cluster, so just wire them together and imagine they're in a
row instead of it being more like a circle.

The rows are just wire. Individual segments connecting two switches. I used a
pair of pointy tweezers to put little hooks on the end of each segment. The idea
is to let the Solder do most of the work. If a day ever comes where you have to
desolder one of these, you'll be glad you didn't aggressively wrap it.

### Columns

The columns need to be wired with diodes. You can probably wire the entire
column with the diode stems, but I chose to add some wire segments so it would
look clearer for this guide.



The diodes need the black bar facing away from the key. The other guides
disagree, but they don't use QMK.

To use wire segments here, I soldered the end of the diode with the black bar to
the wire first, then placed the other stem on the switch, positioned the diode
where I wanted it and then bet the diode stem into a hook around the switch
terminal.

I also made a habit of keeping the trimmed diode stems to use as bridges if
needed later.

**Note:** Column 6 only has one key at this point.

### Ergodox Compatibility Inner Columns

**This is an optional step, and can be done as a mod after you're done** so
there's no pressure to make this decision now.

Ergodoxes have an additional three keys in columns 6 & 7. Do you want them on
your Dactyl?

I own an Ergodox-EZ as well, and want to use the same keymap for both. So I
added the extra switches below the thumb clusters as Cherry ML switches. If you
don't care about a consistent experience between a Dactyl and Ergodox, or even
if you do, it's a matter of personal preference.

Wherever you put them, they're wired into rows 0,1 and 3. Either way, you need
to wire columns 6 and 7 to the top inner most key in the thumb cluster, so
columns 6 & 7 are going to be live.

If you go with MLs, you can put them wherever you want, but be careful measuring
where the holes go, you only get one shot.

**TODO:** CherryML switch hole specs.

## The Matrix Has You

Actually, you have it! Congratulations on having gotten this far.

## Wiring The Right Half

### Wiring the Teensy

We have to start off with the obligatory wiring diagram

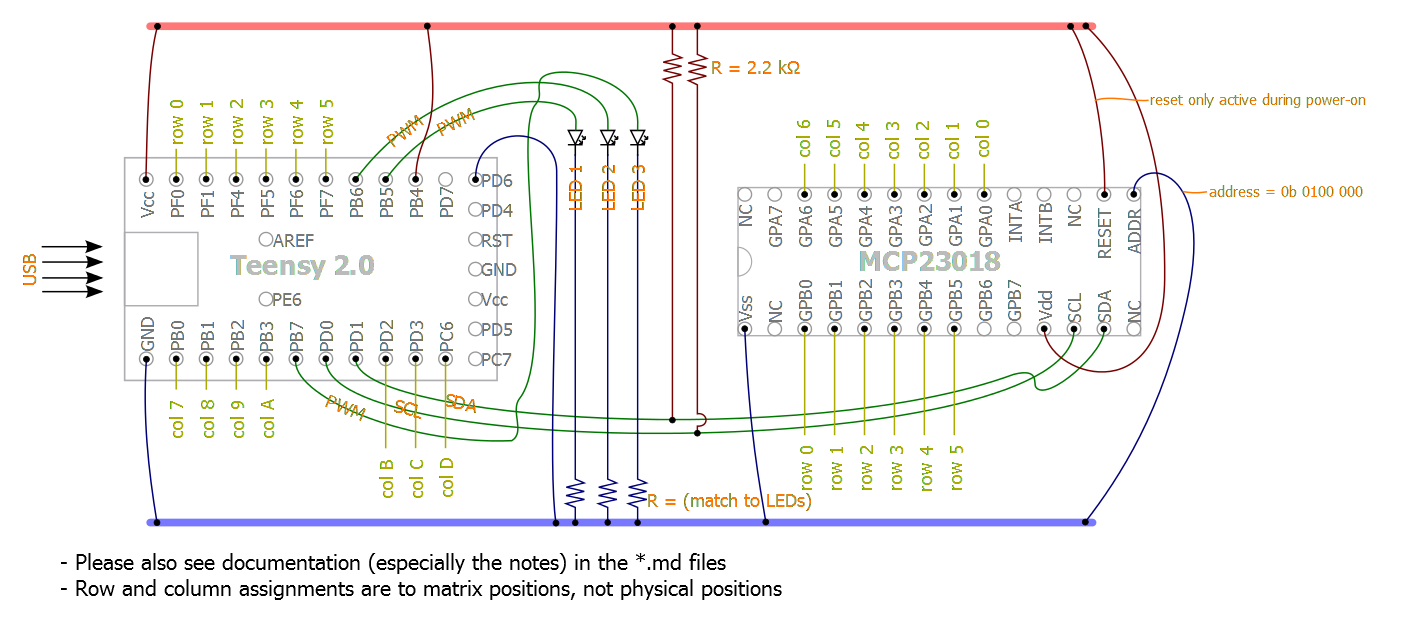
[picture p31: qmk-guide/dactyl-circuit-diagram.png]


Notice the row numbers are different from the other guides to match the QMK
key codes we're using.

I started off by breadboarding this whole project, but I also burnt out the
teensy's bootloader.
[My misadventures wiring a Dactyl](http://joedevivo.com/2017/05/20/building-a-qmk-dactyl.html)
are a fun read if you feel like this is too hard. I've been there.

Here's the pinout mappings for the rows and columns:

| Row | Wire Color | Teensy Pin |
|---|---|---|
| 0 | Yellow | PF0 |
| 1 | Orange | PF1 |
| 2 | Green | PF4 |
| 3 | Brown | PF5 |
| 4 | Blue | PF6 |
| 5 | Purple | PF7 |

| Column | Wire Color | Teensy Pin |
|---|---|---|
| 7 | Red | PB0 |
| 8 | Yellow | PB1 |
| 9 | Orange | PB2 |
| A | Green | PB3 |
| B | Brown | PD2 |
| C | Blue | PD3 |
| D | Purple | PC6 |

Wiring the teensy involves looping the 30AWG wire through the Teensy's pinouts,
I went through twice, and then dabbed a little solder. If you are ok with
possibly wasting a little wire, you can use longer wire to solder up the Teensy
and then breadboard with those wires. There's no room for pins in the case, so
this is the best way to test it out.

Here's my breadboarded version, almost done. (missing the reset wire to the MCP
in this photo)

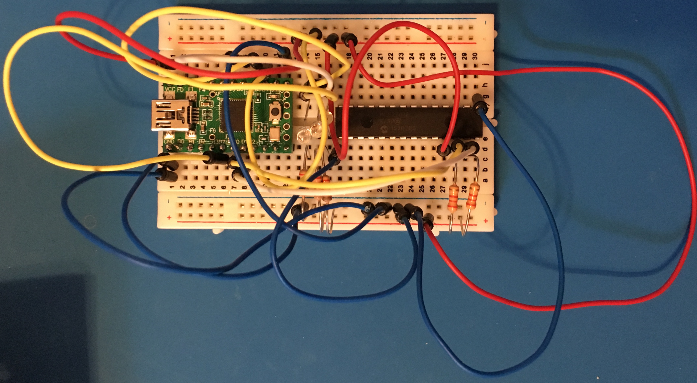
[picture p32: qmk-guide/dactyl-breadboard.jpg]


Yours will look similar, but with the Teensy coming from off board with a bunch
of wires. You don't have to breadboard the columns and rows for the teensy, you
can test them by clipping them to the right spot on the matrix you built.

Columns and rows run by the MCP (Greetings, program!) will be accessible via the
breadboard.

Here's what that looks like wired in.



Fortunately, QMK *will* let you just run the right half, so you can check in at
this point and see how that all works,

### The TRRS Jack

In an effort to move some of the bulk away from the Teensy, I put the pull up
resistors as close to the jack as I could.

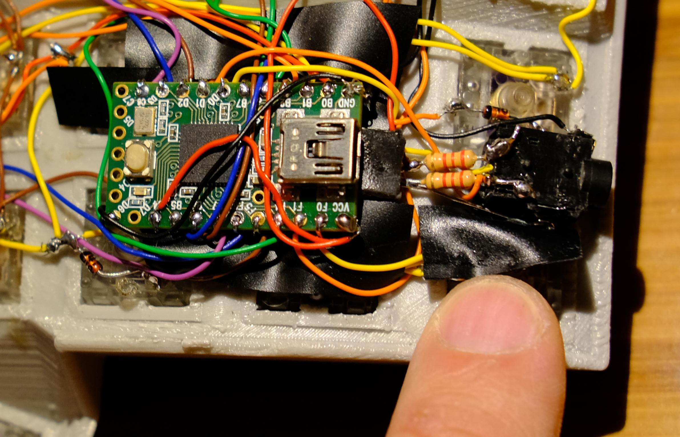
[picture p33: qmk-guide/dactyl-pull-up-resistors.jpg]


I wired the two 2.2k resistors to the bottom two terminals on the TRRS jack,
then wired the SCL(PD0) and SDA(PD1) to the resistor leg going into the jack.
Then soldered the outside legs together and ran a wire from Vcc to those outside
legs, and from them to a third terminal on the TRRS jack. Now all you need is to
run GND to the fourth terminal.

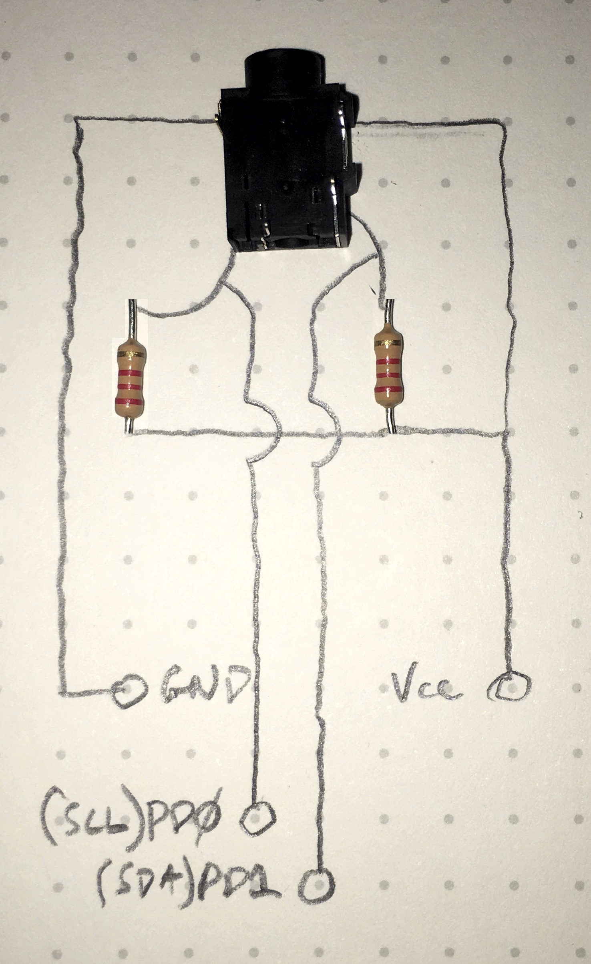
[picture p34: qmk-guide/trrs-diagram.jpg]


## Wiring The Left Half

### Wiring the I/O Expander

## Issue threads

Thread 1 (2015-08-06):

Do you have a website / kickstarter etc for this?

jasonm23, 2015-08-06:
because it's awesome!

kastiglione, 2015-08-06:
:heavy_plus_sign: :one:

Nathan219, 2016-02-06:
:+1: Yes please

pupeno, 2016-11-16:
Agreed. We'll... That is if it was a full keyboard. I would buy it right away.

pycy, 2017-05-08:
+1

Eloren1, 2021-12-26:
Found them here https://ergohaven.xyz/keyboards

BTW, @adereth , does project license allow to sell them?

jaredjennings, 2021-12-27:
Adereth shows up occasionally but I haven't seen him here lately.

That site looks pretty nice. Not sure where in the world it is, but it seems buying across continents gets expensive, so although code flies around the world, commerce doesn't. The sites I know selling physical keyboards are ohkeycaps.com, diykeyboards.com, bastardkb.com.

See also https://reddit.com/r/ErgoMechKeyboards. There was a discussion there about licensing and sharing - can't find it now, will update later.

Forks of this code that I've heard of are the Dactyl Manuform (started by tshort, itself notably forked by carbonfet, and available as a web app at dactyl.siskam.link), the DMOTE (which begat the Concertina), the Lagrange, and of course my own fork, where I've tried many ideas, most of which have failed.

My experience 3D-printing this original Adereth Dactyl using PLA in a filament-squirting printer is that some parts of the model are thin enough that they break too easily when you put the keyswitches in. But I can't stop wanting to customize this two-piece design, rather than the Dactyl Manuform.

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

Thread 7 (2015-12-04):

TRRS sucks

adereth, 2015-12-04:
I should pick something better.  Probably RJ45.

mathias, 2015-12-19:
RJ-11? https://www.sparkfun.com/products/132 +  http://www.amazon.com/5-7ft-Black-Telephone-Extension-Cable/dp/B0099L1H94/ maybe.

zorglups, 2017-08-24:
Yes. RJ11 would be a good ideabut probably more difficult for people to source/create.

On my Ergodox, I removed te sockets and soldered the cables straight to the board. Anyway... The 2 halves always travel in the same bag ;-)

I'll do a direct connection on the Dactyl too and this keyboard being less portable will even travel less.

My 2 cents.

TobiasWegener, 2018-04-14:
Hey everybody,
I am planning to build a Dactyl and was thinking about to use a HDMI cable (or VGA) connector and then directly combine the rows on both sides. These I will than directly connect to the Teensy board.
Am I missing something or should that be fine?

gagbo, 2018-11-09:
Hi,

Why do you prefer running a video cable to a RJ45 ? Just curious at this point, I'm trying to plan a dactyl build

mr-ubik, 2019-02-24:
What about USB-Type C? I saw it thrown around on GH.

TobiasWegener, 2019-03-09:
> Hi,
>
> Why do you prefer running a video cable to a RJ45 ? Just curious at this point, I'm trying to plan a dactyl build

Hi the reasons are that HMDI is an absolute standard cable (easy to get). Furthermore, it has 19 pins and thus makes a direct connection of the rows and columns with the teensy possible, which makes programming the teensy and the use of easy AVR and QMK as simple as for normal (not splitted) boards.

The problem is USB-Type C can be that it is unidirectional, so u have to be very careful that u don't mess the pin out when the plug is the other way around. I have seen people struggle with this.

And when size is a concern u can still use HDMI mini, which has all the benefits stated above.
I hope that answers your question.
The biggest draw back with HDMI is probably that is still bigger than the TRRS.
If somebody has counter points I missed, please let me know. :)

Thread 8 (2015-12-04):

Document PCB manufacturing and wiring

adereth, 2015-12-04:

jasonm23, 2015-12-10:
for reference https://github.com/adereth/dactyl-keyboard/pull/11

BubblesToTheLimit, 2015-12-10:
@adereth How much have you paid for printing the modell?
Printing this at some 3d printing service seems extremely costy (~ 600€)

adereth, 2015-12-10:
It comes out to $225 if you print it through Shapeways in their cheapest material: https://www.shapeways.com/shops/bespokeys

mathias, 2016-01-01:
I'm guessing the 220 Ohm (red red brown) resistors on the Teensy are these pull-up resistors on the Ergo Dox:

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

joedevivo, 2017-05-02:
The 220s look like they's supposed to be wired to LEDs, which aren't pictured anywhere. It'd be nice to call that out somewhere and talk a little about how you'd choose a resistor based on LED color. I tried, but just haven't been able to figure out how to turn Ohm's law into Red LED = 220 Ohms.

joedevivo, 2017-05-02:
I'm also trying to figure out the best way to wire it up to work as seamlessly with qmk as possible.

The good news is that at this point I'm just gathering parts, so I should be able to log the whole thing.

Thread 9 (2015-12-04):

Add ALPS compatibility

adereth, 2015-12-04:

sbuller, 2017-09-08:
I see some ALPS code in dactyl.clj, but I can't really tell if this is currently enabled or not. Or how to enable if it is not. What is the status of this?

silverhook, 2017-12-28:
I see there is a Matias version of the LightCycle now, but not one for normal Dactyl. Could you please update that as well?

jaredjennings, 2018-01-07:
If you run the dactyl.clj that's currently in the repository, you'll get SCAD output with Matias-shaped holes in it. See the [single-plate](https://github.com/adereth/dactyl-keyboard/blob/e0416e329032b3648a86e53656906702603dbeb0/src/dactyl_keyboard/dactyl.clj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) vs. [old-single-plate](https://github.com/adereth/dactyl-keyboard/blob/e0416e329032b3648a86e53656906702603dbeb0/src/dactyl_keyboard/dactyl.clj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) functions (single-plate is what gets used later on in the code).

silverhook, 2018-01-08:
@jaredjennings Thanks :)

In the meantime I already ordered some Kailh BOX Jade switches to try them out in this board. Good to know i can fall back to my trusted Matias if need be.

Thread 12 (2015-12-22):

F-keys

jahkeup, 2015-12-22:
Any chance a row could be added to the top for F1-12?

mathias, 2016-01-01:
There's a range here that controls how many rows the keyboard has: https://github.com/adereth/dactyl-keyboard/blob/master/src/dactyl_keyboard/dactyl.clj#L90

The trick would be that you'd need to add another row to the controller, the firmware, and the PCBs. The electronics seem very inspired by the Ergo Dox (but I haven't dug in yet) - so I'm not sure if the controller and the MCP23018 has enough "inputs" to add another row. Maybe someone who has tinkered more with the electronics can chime in here.

laialbert, 2016-01-31:
I tried doing just that and it does create another row for F keys, if you change the range to (range -1 5). However, I couldn't figure out how to change the back, right, and left walls to accommodate the additional row.

In looking into using the Teensy controller, it seems that you can probably accommodate a row of F keys (just barely). There's the Phantom Tenkeyless (https://deskthority.net/wiki/Phantom) keyboard that was built on the Teensy 2.0. If there aren't enough pins, then you'd need to use the Teensy++ 2.0, which has enough pins. (My understanding is that the minimum number of pins you need is number of rows and columns in your keyboard, plus 1).

Regardless, you'd have to adjust the keyboard matrix and update the firmware to match. I haven't looked into this enough to figure out how to actually do it.

linnemannr, 2016-03-23:
I did look into this with the ergodox electronics, and the dactyl is a variant of the ergodox with the same keycount. With the teensy 2.0 and the 16 bit IO expander, you do have enough pins to add an additional row and column to each hand and more. I too am looking in to adding the function keys. If I can grok clojure enough to parameterize the walls on the number of rows (and hopefully columns) I'll make a pull request. I can barely elisp right now so it might be a tall order :/ My 3d printer and gateron red keyswitches are beckoning...

plo009, 2016-11-11:
It would be great if anyone has made any progress on adding the function keys could make an update here, using a ergodox now and really think the function keys would be very handy.

PierreKircher, 2016-11-11:
why not just use a layer ? keybinding + numberkey = f-key usually the less keys the better

plo009, 2016-11-11:
Well for cases where you need to press more than just the function key, e.g. alt + f4 etc

PierreKircher, 2016-11-11:
even thats possible with mappings .. if you bind the switch of the num row to a different key .. say the "meta|win|apple" key on the thumb cluster  .. to archive that ..

pupeno, 2016-11-16:
I'd also like to have F keys, or even better, extra rows/columns of programmable keys.

nickhristov, 2016-11-22:
+1 please add another row.

mathias, 2016-11-22:
See https://github.com/adereth/dactyl-keyboard/issues/12#issuecomment-168314746 -- this is parameterized for the 3D model. You'll have to learn a bit about the Ergo Dox electronics and firmware to get that extra row in there and program it to be f-keys.

I'd guess that pull requests for this are happily accepted and the community can help support it, so if you want it enough, I encourage you to give it a shot.

adereth, 2016-11-22:
Yes, pull requests are happily accepted.

Note that adding a row is going to require changing a bunch of other things and the naive approach of just adding the row will not work.  If you look at the current number row, you'll see that back of the caps are missing each other by about a millimeter.  With the current curvature, an additional row  will result in the caps overlapping, so that needs to be changed.

I'm planning on doing a build that actually has the number row removed and I'll use the function layer on the home row for numbers and the top row for F1-F12.  The work I'm planning to do to make it easy to remove a row will also involve me making the back wall's shape automatically adjust to the back row, so that should make this a little easier.

I'm not going to tell anybody how to live their life, but I highly recommend getting more comfortable with the function layer.  I'll point out that the thumb cluster on the Dactyl is much more accessible than on the Ergodox and with R1 caps on the top two keys, it's very comfortable to hold them down while pressing any of the keys on the main keywell.

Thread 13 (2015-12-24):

which switches will fit?

roy, 2015-12-24:
I understand that you used gatheron switches in your current keyboards.
I'd like to put in mx brown switches, but I don't know if I need to use pcb or plate mounted switches.
Do you happen to know this?

mathias, 2015-12-30:
I'm fairly certain that Gateron makes their switches the same size as Cherry MX switches.

Most DIY keyboards use plate-mounted switches: they "snap in" to a plate rather than get soldered onto a PCB. So for this keyboard, you'll need plate-mount Cherry MX switches.

roy, 2015-12-30:
Awesome, thanks :)

Closed 2015-12-30.

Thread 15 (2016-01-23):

Issue with stl in the /things/

oilydog, 2016-01-23:
I uploaded the dactyl top right to a 3d printer website in Aus, and this is the quote. http://i.imgur.com/KPVQxwV.png
Im going to guess that _maybe_ that are not just doing the usual aussie overcharging.

mathias, 2016-02-03:
Looks like the size is huge -- I'd check the units used and what they expect?

adereth, 2016-11-30:
Yes, the units should be millimeters.  If that's already correct, I recommend using a different print shop 😄

Closed 2016-11-30.

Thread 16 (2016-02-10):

Teensy firmware

iplus, 2016-02-10:
Can you commit code for Teensy controller according to your matrix?

arhi, 2016-04-21:
any news on this? what is the MCP chip used to connect the other side? MCP23017? MCP23S17? (i2c or spi or ?) are you using the same firmware as ergodox ( https://github.com/benblazak/ergodox-firmware ) or ?

BubblesToTheLimit, 2016-08-06:
I'm pretty sure he is using the ergodox-firmware (https://github.com/benblazak/ergodox-firmware ). He uses the same controllers (Teensy 2.0 and MCP23018 I/O expander) and the wiring that can be seen in his rough guide is almost identical (4/6) to how the matrix is defined in https://github.com/benblazak/ergodox-firmware/blob/master/src/keyboard/ergodox/matrix.h

EricGebhart, 2016-11-26:
@adereth  How different is it ? Why the modifications ?  The chips are indeed the same as ergodox.

If it were ergodox compatible we could just use the QMK firmware directly.

What would it take to make it compatible with QMK ?

EricGebhart, 2016-11-26:
Presumably [this schematic](https://github.com/ErgoDox-EZ/docs/blob/557cbdaf66f672011447fcc757e8fecd92837648/ErgoDox%20EZ%20Schematic.pdf) could be followed and it would be compatible with ergodox-ez.

joedevivo, 2017-05-21:
I wrote up a whole thing about [Wiring a Dactyl for QMK/Ergodox-EZ](http://joedevivo.com/2017/05/20/building-a-qmk-dactyl.html) and I'm happy to roll some of that into the guide if that's helpful.

EricGebhart, 2017-05-22:
Nice article. Yes I think some documentation on wiring it as an ez would be great. The wiring doc is not very good as it is. And using the ez code makes sense.

Alevale, 2023-06-30:
> I wrote up a whole thing about [Wiring a Dactyl for QMK/Ergodox-EZ](http://joedevivo.com/2017/05/20/building-a-qmk-dactyl.html) and I'm happy to roll some of that into the guide if that's helpful.

Hey! Do you happen to have something at hand for a COMPLETE begginner? I would really love to build something to replace my 20-30 years old kinesis Advantage pro.. but I'm really scared of all of the wiring and not having enough info to build it myself with my limited knowledge (I feel like there's too many issues, hardware, software and hability to make it 😢 )

Many thanks!

Alevale, 2023-06-30:
> I wrote up a whole thing about [Wiring a Dactyl for QMK/Ergodox-EZ](http://joedevivo.com/2017/05/20/building-a-qmk-dactyl.html) and I'm happy to roll some of that into the guide if that's helpful.

@joedevivo Hey! Do you happen to have something at hand for a COMPLETE begginner? I would really love to build something to replace my 20-30 years old kinesis Advantage pro.. but I'm really scared of all of the wiring and not having enough info to build it myself with my limited knowledge (I feel like there's too many issues, hardware, software and hability to make it 😢 )

Many thanks!

jaredjennings, 2023-07-06:
@Alevale there has not been a great deal of activity on this Github repository or its issues in the past three years or so. You can find some electronics videos like [this one](https://www.youtube.com/watch?v=hjml-K-pV4E) on Youtube if you search "keyswitch matrix" or "handwired keyboard." People often use a pair of Pro Micros these days rather than a Teensy and an I/O extender chip. You can find people and ask questions at https://lemmy.world/c/ergomechkeyboards or geekhack.org. Depending on the physical condition of your Kinesis Advantage, you may be interested in https://michael.stapelberg.ch/posts/2020-07-09-kint-kinesis-keyboard-controller/

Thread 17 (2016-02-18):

Getting one?

kastiglione, 2016-02-18:
I have a very uninformed question: are there any companies that would produce a dactyl keyboard from the sources and information here?

theelectricwiz, 2016-05-17:
I'm looking at the same thing. He's got the case on Shapeways http://www.shapeways.com/search?q=dactyl&type=

jonleung, 2016-07-21:
I would totally buy if that was an option...

ChunkLightTuna, 2016-07-21:
How much ya wanna pay?

kastiglione, 2016-07-21:
What's the market rate?

roy, 2016-07-22:
I think retail price should be around $300 to $400

jonleung, 2016-07-23:
That works for me : )

If anyone wants to build one, lemme know and I'd be down to buy it : )

StevenTammen, 2016-08-27:
Would also buy a keyboard if someone else would build it.

pupeno, 2016-11-16:
I'd also like to get one.

bthezebra, 2016-12-15:
I would also like one :)

roy, 2016-12-15:
I finally made one. Typing on it right now :)

bthezebra, 2016-12-16:
Hey Roy would you mind posting a couple of pictures of yours? I love to see your design. Did you end up going the hand wired route or did you cut a custom pcb?

roy, 2016-12-27:
Hi bthezebra, I went with the hand wired approach. Mostly because I have a little experience with soldering and none whatsoever with making a pcb, let alone a flexible one. Although it seems I used thick wires and the wrong trrs mounts cause the top and bottom don't fit anymore. I just bought a 3d printer so I can try out a couple things now for the bottom pieces.

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

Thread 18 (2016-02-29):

Right hand PCB design missing column connection to teensy

krakitine, 2016-02-29:
I don't see the line connecting columns 4 and 5 back to the teensy

Below is the left hand pcb with the columns I'm talking about marked in RED, these are missing on the right
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

Side note, why is there a duplicate of the ttrs-teensy circuit on the left hand (marked yellow)?

adereth, 2016-03-07:
Glad that people are starting to look at it in so much detail!  You are correct.  I haven't gotten the design for those columns yet and have them just wired up with wires in my current build.

rybern, 2017-05-16:
Just to clarify - the PCB specs are not currently up to date with the models, right?

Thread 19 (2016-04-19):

Kinesis Circuit Boards

lewismoten, 2016-04-19:
I've got a couple Kinesis keyboards myself. I'm impressed at the similarities - although the keycaps are a bit smaller in height. Is it possible to put the circuit boards from the Kinesis keyboards into this one? I'm also noticing some missing keys - specifically the rubber function keys on the top row.

j9ac9k, 2016-04-22:
Considering the kinesis circuit boards are not flexible, I would imagine fitment here would be a tall order.  I doubt there is any way to say for sure without someone actually trying it.

laialbert, 2016-08-24:
The kinesis circuit boards for the keyless are indeed flexible. However, I would doubt that the circuit boards would fit as I'd think that everything would have to magically align.

PierreKircher, 2016-08-24:
they dont fit at all ... keywell spacing is different .. but you can create your own flex pcbs just like andereth proposed

adereth, 2016-11-30:
Sorry, but the Kinesis PCBs will not work in the Dactyl for several reasons:

1. The exact spacing of the switches is different.  I did not duplicate the Kinesis layout out of concern for legal liability.

2. The Kinesis PCB under the main keywells has no ICs on it.  All the logic boards are in a separate board that is housed in the center of the keyboard.

3. The Kinesis PCB extends beyond the keywells.  I wanted the Dactyl to have the smallest footprint possible.

Closed 2016-11-30.

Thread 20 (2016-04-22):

keycaps

arhi, 2016-04-22:
Hi,
any source for keycaps you can offer? I can get cherry blue keys I want from wasd keyboards for e.g. but they sell keycaps that are different for every row in the keyboard... if I look to get keys I have to chose the row info ...

http://support.wasdkeyboards.com/customer/portal/articles/1366948-keycap-compatibility

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

so what to order?!

j9ac9k, 2016-04-22:
For keyboards with curved contours you generally want keycaps that are SA row 3, or DSA keycaps, I would imagine trying to use a cherry/OEM profile could be problematic, but then again, I'm speculating.

arhi, 2016-04-22:
thanks for the info @j9ac9k about R3 !! makes sense :)
as for DSA, never heard about those till now, quick google shows
http://pimpmykeyboard.com/dsa-pbt-abs-blank-keycap-sets/
that's something that would work good on dactyl ? any other source you could recommend? I get body from shapeways, I'll get keys from mouser/digikey/wasd, so it's keycaps that I need to figure out now where to get from :D and I'm having troubles locating a good source :(

j9ac9k, 2016-04-22:
Probably the most popular DSA profile is the granite keycap set: https://www.massdrop.com/buy/granite-keycap-set (orders are complete, you can usually find them second hand in /r/mechmarket ).

I can't imagine the DSA keycaps wouldn't work well with Dactyl, but only someone w/ one of these keyboards could say for sure either way.

arhi, 2016-04-22:
yeah would be cool to get info from someone that actually tried some profile on dactyl :D ... not sure why @adereth  didn't add to doc whet keys he is using (these on his pictures don't look like what DSA looks on pictures I'm googling now) ... looking at examples on http://keypuller.com/ what @adereth have on pictures looks like SA profile (looks like there's like whole bunch of different profiles for keys available, I had no idea!!)

j9ac9k, 2016-04-22:
Mechanical Keyboards are a very personal preference oriented hobby, there are loads of options out there, the right one, being the one you like.

If you're new to the mechanical keyboard world, this project may be a bit of a big jump into it.  If you're still interested in knowing what typing on a contoured keyboard is like, consider purchasing a Kinesis Advantage keyboard (I have one, it's awesome!).  The number of options with the keyboard is very limited, however what you get in the mail is fully functional, so that may be a good place to start if you're not sure what you want just yet.

arhi, 2016-04-22:
electronics and 3d printing are "easy" for me :D ... and I'm making this one "for someone" ... I was also suggesting http://www.kinesis-ergo.com/shop/advantage-for-pc-mac/ for him but he insist in dactyl as I can make any custom layout for him and he needs that .. kinesis layout is not working for him (heavy emacs user) ... so I took on to myself to do it for him ... he's heavy mechanical keyboard user but is not interested in building, assembling etc ... while I'm builder :) who just use regular old split hand keyboards .. they work more then good enough for my need :) ... I'd personally first purchase few keys of different profile and test them myself but problem living in the middle of nowhere is that it's not that simple to get samples and shipping cost is killing a will to continue project :(

thanks a bunch for the help!! reading now on the profiles looks like there's significant documentation available... I'll get some measurements so I can print keycaps myself and try how they feel before I order a full pack of keycaps :D (thankfully I make 3d printers so printing few caps would not be a problem :D )

vIiRuS, 2016-04-22:
Here is a parametric keycap that has configurations for SA (different rows) and DSA.
I'd personally go with the DSA, because I like the low profile they have and the symmetry of the key.

arhi, 2016-04-22:
found it few hours ago :D DSA (type 5) works perfectly

adereth, 2016-04-24:
I designed it to work with fully contoured SA key caps, but I've tried it with every profile and they all work well.  I may eventually do different designs that fit the lower profiles more tightly.

arhi, 2016-04-24:
@adereth thanks for the info, so the "glamour" image is with SA profile?

adereth, 2016-04-24:
Yes, that pic is all Row 3 SA caps, but I use fully contoured on my personal build.

ChunkLightTuna, 2016-05-28:
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
here's mine with DSA's from pimpmykeyboard

TartanLlama, 2017-03-10:
@adereth Do you have a list of the sizes and rows of the keys you use with contoured SA sets? I'm thinking about jumping on [this groupbuy](https://en.zfrontier.com/collections/keysets/products/sa-max-ashen), but only if it'd fill a Dactyl.

adereth, 2017-03-10:
I use R1 - R4 for the top 4 rows, then flipped R1 for the bottom.  I've used both R3 and R2/R4 for the 2u keys on the thumbs and everything from R1 - R3 for the 1u keys on the thumbs.  That group buy doesn't have enough 2u keys.  You may need to fill it out by ordering some blanks:

http://pimpmykeyboard.com/sa-2-space-pack-of-4/

zorglups, 2017-08-24:
@adereth I read somewhere else that people with larger hands should use dsa profiles (at least for the thumbs). Do you "confirm" that?
Hum... Could I ask... How long are hands... Say from the junction hand-wrist to the end of the longest finger.

Thanks.

TylerPham, 2021-05-06:
@adereth do you think mixing a sculpted SA for the alpha's and a set of DSA's for the thumb cluster would be more friendly for smaller hands/less stretching?

The sculp and the curve would reduce finger travel while the shortened DSA caps for the clusters would allow the user to keep a slightly more closed hand.

Also, do you think there is a significant difference between sculpted SA and uniform SA row 3 in terms of comfort/reach?

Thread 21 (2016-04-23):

Which Unit Size .STL File mm, cm, inches?

thecmachine, 2016-04-23:
I'm trying to get 3d printer quotes in Manhattan and I have no idea what I'm doing as far as 3d printing goes.  Can Someone fill me in?  I'm going to try to compile a shareable google spreadsheet for 3d printing estimates on different Websites and share it on /r/mechanicalkeyboards.

Please halp.

adereth, 2016-04-24:
It's all in millimeters.  The spreadsheet is a great idea... it might also make sense to just include it in the documentation in the repo.

thecmachine, 2016-04-24:
I'll be happy to put the spreadsheet together.  I finally found an online tool that would tell me how large the plans were rendered at different scales and neither inches or cm would yield a Keyboard fit for anyone other than a giant.  Does anyone have any recommendations on the "least premium, most appropriate plastic/filament strength"?  I'm looking at higher infill/shell PLA as the lowest quality/minimum medium for printing, then including prices for ABS also.  Does anyone recommend establishing a higher quality material as a minimum strength print?

Closed 2016-04-24.

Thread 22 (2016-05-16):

Measures of STL files in /things/

macmakkara, 2016-05-16:
Hi,
Are these correct mesures for STL files.
16.47 x 14.22 x 5.83 cm for bottom left.
16.85 x 14.11 x 6.86 cm for top left.
These are same for both sides cause they are just mirrored.
Are these measures correct?

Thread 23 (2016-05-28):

STL's in "things" and STL's on shapeways? same version

arhi, 2016-05-28:
I see that there were some updates on the "things" stl's but I don't see if shapeways already have the latest ones or only the original ones?
Talking about these from @adereth  https://www.shapeways.com/designer/adereth/creations

I can easily upload STL's from things folder from git, it comes out as same price, but I'd rather click to order ones uploaded by the designer :D

robertdale, 2016-11-04:
My bottom-left and bottom-right parts just got kicked back from Shapeways. I was following @adereth's advice for printing in PLA by uploading the templates myself.  I'm fairly certain I used the defaults in git. I'll re-upload to be sure.

Reason: Thin Walls
Description: This area will not print cleanly, if this is excess geometry, consider removing or cleaning up. For more information visit: https://www.shapeways.com/materials/pla
Find additional information in the attached image.

robertdale, 2016-11-04:
Just uploaded the originals and it complains about thin walls. But now they have a button for fixing thin walls. I'll let you know how that goes.

adereth, 2016-11-04:
I recommend using the "Print It Anyway" option.  That's what I did for my builds.  I would not use their automatic fixer.

Also, I found their PLA print to be extremely poor quality.  I recommend either using their "Strong and Flexible" material for a build that you actually want to use for a long time.  If you insist on PLA, you should try a local printshop instead.  Several people have had luck using 3Dhubs for that.

robertdale, 2016-11-04:
@adereth  They actually refused to build it after ordering and some preprocessing stage.  That's why I was trying the automatic fixer. But it doesn't seem to actually fix it.  Going forward, I plan on buying from your store for the final build. I just getting something cheap to experiment with.  I'd rather destroy the PLA prints before building the final version. In fact, I really only need the tops. The bottoms would have been nice to have to make sure I have the angles right but I hope I can compare to my Advantage.

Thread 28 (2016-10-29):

FDM friendly model

Cka3, 2016-10-29:
Please consider making fdm friendly model, so more people can enjoy this beautifully designed keyboard. Thanks.

evamvid, 2016-11-04:
This is definitely fdm-doable (I'm printing the second half bottom as we speak), but there could definitely be improvements.

The biggest thing would probably be doing the legs on the bottom half seperately. If there was some kind of captured nut mount on the bottom, it would reduce printing time, reduce the amount of support needed (saving time, quality, and plastic), and allow you to do the legs either out of a different material or with higher infill for more strength compared to the rest of the model.

danielfullmer, 2016-11-04:
In case anyone is interested, I made an alternative bottom piece which is much easier to print on FDM printers. See:
https://github.com/danielfullmer/dactyl-keyboard/blob/master/things/dactyl-bottom-right.stl

evamvid, 2016-11-06:
This is a much easier print. What could be done about the top section?

I printed one of yours (plus a right hand of the original), so I may end up with an asymmetric dactyl!

danielfullmer, 2016-11-06:
I should have mentioned, my fork is based on [kennykaye/dactyl-keyboard](https://github.com/kennykaye/dactyl-keyboard), which, among other things, uses 1.5 size keycaps on the outside column. I haven't checked if my bottom piece would actually fit the original adereth top piece.

roy, 2016-12-01:
@danielfullmer is it much work to do the same with the original? I'm currently making the keyboard as well and wiring by hand caused the casing not to fit. Your version would make it much easier.

danielfullmer, 2016-12-02:
The code is a bit messy at the moment, but I've tried to cherry pick my code onto the original adereth branch in [danielfullmer/adereth-new-bottom](https://github.com/danielfullmer/dactyl-keyboard/tree/adereth-new-bottom).

The stl files are these:
https://github.com/danielfullmer/dactyl-keyboard/blob/adereth-new-bottom/things/dactyl-bottom-left.stl
https://github.com/danielfullmer/dactyl-keyboard/blob/adereth-new-bottom/things/dactyl-bottom-right.stl

The kennykaye branch does something different with the clearances, so I can't give any guarantee that this will necessarily fit properly.  I haven't printed this version or anything.

I also use a slim hdmi cable to connect the two halves, so there is an hdmi cutout in the thumb cluster. It wouldn't be too difficult to change to a trrs connector if needed.

roy, 2016-12-04:
Ah that's very smart to use an hdmi cable. Although you miss compatibility with ergodox firmware then. Thanks for the other stl files, I'll check them out

tshort, 2017-03-11:
I've got a work-in-progress fork that works reasonably well on FDM printers.

https://github.com/tshort/dactyl-keyboard

It works pretty well on FDM printers because the walls go straight up. Here are other changes in this fork:

* Thumb cluster from the [ManuForm](https://github.com/jeffgran/ManuForm)
* Parametric rows (4-6) and columns (5 and up)
* Parametric tilting and curvature
* RJ-9 for interconnection

To not clutter up this issue, you could post any follow-ups to the following issue at my fork:

* https://github.com/tshort/dactyl-keyboard/issues/2

I'm new to Clojure, but it's a lot of fun playing with @adereth's code and watch code build things.

joedevivo, 2017-07-14:
@danielfullmer how do you fasten the top and bottom pieces of your design together?

danielfullmer, 2017-07-14:
@joedevivo I currently don't have any fastening between the two pieces. It holds together fairly well for normal typing use. I had intended to figure out something more secure, but I'll probably end up doing something based on tshort's fork for my next version--which is just a single piece anyway.

joedevivo, 2017-07-14:
@danielfullmer ahh, the ol' gravity fastener ;) It'd be nice if there was a way for the pieces to clip together, since I like a good two tone effect. Mind posting some photos of how it looks assembled? particularly the inside. That base looks so roomy, so much possibility in there.

jrozner, 2018-06-05:
@evamvid could you and/or anyone else who has printed this with and FDM printer share some details about material used, printers, and settings? Working on printing this with PETG on my Prusa MK3 and about an hour in it's not looking terrible but it's also not looking amazing? Also, the amount of plastic being using to print the supports vs the model itself is a little concerning. Haven't done much with PETG yet and still dialing the the settings, especially for this manufacturer (eSUN).

jaredjennings, 2018-06-05:
@jrozner, I don't have my own printer, so I split it up in ~1.5 hour pieces. See jaredjennings/dactyl-keyboard. For most of the pieces, adding several layers of mandatory support, raft and brim, I've been able to rotate them up on a corner before slicing, with good results, using Hatchbox PLA.

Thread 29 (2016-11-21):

Change the license for models from CC-BY-NC-SA to CC-BY-SA

silverhook, 2016-11-21:
CC-BY-NC-SA is **neither** a [Free Culture licence](http://freedomdefined.org/Licenses) **nor** an [Open Source Hardware license](http://www.oshwa.org/faq/#noncommercial).

The basic gist is that by restricting the _use_ to only non-commercial you prevent a substantial part of the community from _using_ it for whatever purpose – which in Free Software terms would mean it doesn’t give its users the most essential Freedom 0. In practice the license prevents (anyone except @adereth ) to sell Dactyl as a DIY kit or even just offer 3D prints of its case – whether this was intentional or not.

… or to quote OSHWA’s own FAQ:

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

I see the NC as a blocker for this otherwise awesome-looking keyboard to strive and would suggest to change the license CC-BY-SA-4.0, which is very similar and is still a copyleft license, but without the non-commercial restriction.

P.S. Awesome project BTW! :smile_cat:

Erudition, 2017-04-01:
Agreed, please stick with free culture licenses!
I'm fascinated by the project and certainly considering building one... didn't notice the non-free license at first.

adereth, 2017-04-01:
I've removed the NonCommercial restriction and changed the license to CC-BY-SA.

Closed 2017-04-01.

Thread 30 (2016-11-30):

Schematic / differences from standard ergodox/ergodox -ez

EricGebhart, 2016-11-30:
Hello @adereth

I'm about to put one of these together and I'm wondering if there is a schematic for the keys or how it differs from the standard wiring of the ergodox and ergodox-ez.

I'm considering just following the schematic for the ergodox-ez and using the ergodox firmaware on QMK.

So are their differences ?  Knowing them would make things a little easier.

Thanks,

Eric

adereth, 2016-11-30:
No, I wired it in the exact same configuration as the Ergodox, with the only exception being that the Dactyl doesn't have the inner columns containing 3 keys on each side.  I use Ergodox firmware on my builds.

EricGebhart, 2016-11-30:
Cool.  I saw the fork for the firmware so I wasn't sure if there were hardware differences driving the creation of the keyboard within that firmware.

I've been creating my keymaps.  I use dvorak and bepo layouts so that is one of the reasons I want to use
the QMK firmware.

I'm starting to get all the parts, so I'll be assembling it soon.

Thanks for the quick response.

Eric

Closed 2016-11-30.

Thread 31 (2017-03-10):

Running a group buy

ev0platypus, 2017-03-10:
I don't know another way to reach you so i am going this route.

I just built a this board and posted it up on reddit. I want to do a group buy and i wanted to see if you would have an issue with this. Can you contact me at EvoPlatypus@gmail.com? this is the only way i know how to reach you.

Also, i am adding in wires that are missing to the PCBs and making them into one big sheet. The goal is to supply them to the community so more of this keyboard can be made.

PierreKircher, 2017-03-10:
its opensource .. i doubt adereth has a problem with a GB thats as as if opensource demands it .. design credits are given ( same as with the ergodox ) .. you can reach him on irc .. he usualy hangs out in #geekhack on freenode

nickhristov, 2017-03-10:
+1 would buy

ev0platypus, 2017-03-10:
I just wanted to make sure as i haven't messed with this stuff before.
Better to be annoying than go in blind when it comes to money.

Haven't used IRC in years and even then i didn't use it that much. Was just
hoping to catch him on here but i guess it doesn't really matter.

On Thu, Mar 9, 2017 at 7:54 PM, PierreKircher <notifications@github.com>
wrote:

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

ev0platypus, 2017-03-10:
I will be running a GB through GH after i get some prices. Keep an eye
there.

On Thu, Mar 9, 2017 at 7:59 PM, Nick Hristov <notifications@github.com>
wrote:

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

PierreKircher, 2017-03-10:
why not the regular massdrop way and let em handle it ? .. if there is plenty interrest .. ? ( after the former interrest check ofc)

the problem is buying from some unknown sources .. specialy the first independent group buy is kinder risky . - loads have been screwed over in the past ?

PierreKircher, 2017-03-10:
see issue 29

https://github.com/adereth/dactyl-keyboard/issues/29

unless written consense you would actualy go against the licence

AustinBrister, 2017-03-10:
If it was mass drop I would be all over it.

Sent from my iPhone

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

ev0platypus, 2017-03-10:
I see. would you be willing to give me permission? or change the Licensing?

On Thu, Mar 9, 2017 at 9:18 PM, PierreKircher <notifications@github.com>
wrote:

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

PierreKircher, 2017-03-10:
any andereth can do that .. and you need that in written form

ev0platypus, 2017-03-10:
I don't know how well MD would work with what i am doing though. I am
making the Flex PCB, or at least that is what i was planning.

On Thu, Mar 9, 2017 at 9:28 PM, AustinBrister <notifications@github.com>
wrote:

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

PierreKircher, 2017-03-10:
they work with independend manufacturers .. but you just get payed once they delivered it .. - that way the customer remains safe .. and wont be screwed over .. on the other hand you can be sure there is a demand and you get the money as soon as you deliver your goods

ev0platypus, 2017-03-10:
Sorry i thought i missed something. I was replying to the email and i though it was him that was responding to that. My Bad.

ev0platypus, 2017-03-10:
Either way. I need to get ahold of him. So I will start working on that.

This is my first groupbuy run so i am just going to blunder through it. Started trying to get the feel for who wanted it today. So before i go any farther i am going to get ahold of him. Hopefully.

PierreKircher, 2017-03-10:
so step 1 .. get the agreement

- do your DD

then interrest check on GH
MD runs there own poll .. once it makes it there

they presell em .. gather sales .. keep the cash as in an escrow ( pretty much that will be the case with all unknown entity unless you have valid a biz credit ranking ) ..

you get an purchase order for N amount of units - you take a credit against that purchase order .. - if you hold up your end of the bargain .. they relase the cash to you - all you do is ship N amounts to them .. rest is all done by them - safest way for any customers ..

PierreKircher, 2017-03-10:
tbh .. the manufacturing of the pcb's is the easyest part .. there are plenty pcb house that do flex pcb's .. there are more problems - hight ( arm rest required .. unless you have hovering hands anyway) .. the case is a pain to manufacture unless its shapeway ( VERY Expensive ) .. the only saving i can see is on the pcb's .. and in that case you can run a group buy just for them - my 2 cents

ev0platypus, 2017-03-10:
That is why i wanted to reach out to him was to make sure i wasn't going to
mess it up. The quotes for the Flex PCB i was getting for 1200. Dunno if i
was looking the wrong spot or what. I am sure bulk would bring it down but
i was just doing it for myself.

i know a guy by me that does wood rests. i am going to see if he wants to
join on this.

Again all of this rests on getting the agreement. I appreciate the help.
Kinda new in this space. Got into this hobby because i was bored at home.

On Thu, Mar 9, 2017 at 9:40 PM, PierreKircher <notifications@github.com>
wrote:

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

PierreKircher, 2017-03-10:
http://dirtypcbs.com/store/pcbs

ev0platypus, 2017-03-10:
I saw that before, but it only goes to 10x10cm. I need upwards of 8x8
inches for the whole circuit. It is also 2 layers only which would force
you to insulate it. I might try spreading out the pieces to see what it
would be. A couple of the wires might be to wide.

On Thu, Mar 9, 2017 at 9:47 PM, PierreKircher <notifications@github.com>
wrote:

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

PierreKircher, 2017-03-10:
tbh .. that board is 1 layer .. you wont even need 2 - and you have 1 pcb each side .. ya 10cmx10cm is small .. i agree but as i sayed there are plenty pcb houses in china that do them cheaply .. a mail to dangerousprototypes wont hurt ether ..- as i sayed i rather go 2 small flex + 2 hard pcbs for the thumbclustes .. just like kinesis did it .. seems to work for them over 10 years :)

ev0platypus, 2017-03-10:
That.... is a valid point.

I am trying to reach him through Shapeways. See if he responds there. If
not i will go at it.

Work for me tomorrow will be my DD to learn about licensing and the rules
of all of this.

Thanks again for your help! Time to be annoying to other people ;)

On Thu, Mar 9, 2017 at 9:58 PM, PierreKircher <notifications@github.com>
wrote:

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

adereth, 2017-03-10:
Just sent you an email.  I feel like there are a number of changes that need to be made before doing anything large scale.

Closed 2017-03-10.

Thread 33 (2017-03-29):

Back doesn't fit with wires

postelrich, 2017-03-29:
I cant figure out how i need to move the wires around in order close the back.  I did my best according to the pictures.  Anything pop out to anyone?

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

BubblesToTheLimit, 2017-03-30:
I had the same problem and replaced the thick wires with copper wire.

postelrich, 2017-03-30:
:( I spent all that time stripping the wires in the middle

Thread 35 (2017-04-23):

Pregenerated top-left-with-teensy is for different switch than the rest

nemrod, 2017-04-23:
Top left and top right in /things are both for cherry switches, but only top left with teensy seems to have different switch holes, with no mention of it. Might want to have them be consistent or change the filename to reflect it.

I didn't look closely enough (already printed the right one and assumed they'd be the same) until after I had wasted 40-50 meters of filament and an hour or two of babysitting the print and cleaning away support material. I guess it should be fine to just mirror the right one for the same effect, so I'll do that instead.

Closed 2017-07-11.

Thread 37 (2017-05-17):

Case parts

kadern0, 2017-05-17:
Hi @adereth could you quickly explain which are the differences between all the different stl files under the /things folder?

Which ones should I use to build a cherry-mx one?

Thanks.

chpeer, 2017-09-30:
The lightcycle files are a 'small' version of the dactyl with only 4 rows of keys. Cherry/Matias are cases for the different switch types.
Top/Bottom Left/Right is self explanatory.
If you want to have the teensy in your left half, you can use the according files.
Hope that helps

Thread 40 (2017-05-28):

Troubleshooting connection

postelrich, 2017-05-28:
Finished soldering my dactyl and flashed the ergodox-default qmk firmware using teensy loader. I tried connecting it to my mac and windows10 machines to no avail.  My mac did recognize that a keyboard was attached and brought up the keyboard setup assistant asking to press a button to the right of the left shift button.  Tried that and a bunch of other buttons but nothing happened.  Tried googling but didn't really find anything on how to troubleshoot.

postelrich, 2017-05-30:
Realized there was a link to the firmware here: https://github.com/BubblesToTheLimit/ergodox-firmware

Part of the right half works now, the left doesn't work at all. Progress!

BubblesToTheLimit, 2017-05-30:
Tips for debugging:
- solder on the LEDs which give debug information but are useless once you are done
- make sure you implemented the circuit diagram correctly
- talk to an electronics guy, there are lots of ways of debugging hardware which dont require dactyl-knowledge at all.
- measure the current while you test each switch to ensure your soldering was done right.
- if you are a beginner in building these things like me you are going to bang your head against the wall a whole bunch of times and you actually have to understand most things on your own. There are only so many tips people can give before they do the work for you which is what i experienced.

postelrich, 2017-05-31:
Thanks @BubblesToTheLimit I soldered on the leds and get a 1-2-3 light up when i plug the computer in and then they turn off. Is there a guide that says what the lights mean?

postelrich, 2017-05-31:
Also is there any debug logging that can be gotten?

postelrich, 2017-06-01:
The column to board wires were soldered to the wrong side of the diodes on the left hand and a couple on the right hand. Fixed that and its mostly working now. Some of the thumbpad keys still don't work.

PierreKircher, 2017-06-01:
its mostly again a resistor problem .. schottky diodes have a low voltage forward drop .. usualy around 0.15 and 0.4 V .. if you have a multimeter thats easy enough to test .. pay attention to the small stripe around the diods :)

postelrich, 2017-06-01:
Tried every single key. The left hand is working perfectly. The right thumb cluster isn't but I see some of wires on the buttons need to be switched. That and cleaning up the wires so the back fits and I should be done.

postelrich, 2017-06-02:
OK all buttons working now. Hopefully my logging will be helpful for someone else.

tldr:

- check row/column to board connections are on the right side of the diode
- the right hand thumb cluster wiring switches poles between the switches for some reason but it is correct, follow the pictures.

Closed 2017-06-02.

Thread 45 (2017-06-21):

Guide: document the LEDs on PB5,6,7

ErinCall, 2017-06-21:
The circuit diagram shows 3 LEDs on PB5, PB6, and PB7. They don't show up in the example photos, though, and their purpose isn't clear to me. There's a note that "When the keyboard starts successfully two of the LEDs light up shortly." What does the third one do? Why do we need two LEDs to show successful startup?

Looking at [the ergodox-firmware source](https://github.com/benblazak/ergodox-firmware/blob/d40599230a38fbce1b670cbce561efc1ff0d8071/src/main.c#L57) (that function is defined [here](https://github.com/benblazak/ergodox-firmware/blob/d40599230a38fbce1b670cbce561efc1ff0d8071/src/keyboard/ergodox/controller/teensy-2-0--led.h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)), it seems they all turn on at startup. Is that the case?

Are they supposed to have any use beyond debug?

ErinCall, 2017-06-21:
Oh, and are the associated resistors necessary if the LEDs aren't present? They show up in the example photos, but I don't know if that's because they have to be there or because you left them in after removing the LEDs.

joedevivo, 2017-06-27:
@ErinCall, I'm halfway done with the qmk-guide in this repo, but you can see more about how I wired the LEDs [here](http://joedevivo.com/2017/05/20/building-a-qmk-dactyl.html) for now. With QMK all three will flash on startup, but you can make them do whatever you like in your keymapping. I have a function in my keymapping that lets me represent 0-7 in binary, so I can see which layer is currently active.

I don't know if the resistors are required without the LEDs, but I do know it's a pain to select them, as they're different for each color LED. I'm willing to try leaving the resistors while I test the new PCBs I'm working on [See #49], but I might not get the prototypes back for a while.

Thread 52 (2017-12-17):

Printing lessons learned?

mathias, 2017-12-17:
Hi all,
Before I commit to about 24 hour print time on my home printer, can people share what worked and what didn't for slice settings on their machines? I'm guessing generate supports = yes,  especially for the top halves that curl away from the buildplate (these add about 10 h estimated to my print.)

What about wall thickness? What is a reasonably-good thickness to ensure the key switches are sturdy and that typing won't break it. I've used 1.5-2.0mm thickness on other prints, but I'm wondering if I should do thinner here, or if that is a bad idea?

Obviously, a lot of settings will be different per printer.  I am hoping to use others' experience here a little and modify for my own printer. Thanks!

mathias, 2017-12-17:
I'm also curious whether you all use 100% infill or something less, and if the walls of the model are thick enough for that to matter. It's hard to tell whether infill is being computed or not on my old version of Cura that I use with my printer.

mathias, 2018-01-28:
I've now printed upper-right and upper-left files, and here's some thoughts. YMMV since printers are different. I was printing on my Monoprice Maker Ultimate, with PLA, and settings were (IIRC) 210 degrees F print, 60 degrees F heated bed.

The upper right file was first and I printed with 15% supports, 50% infill (which didn't seem to ever kick in) and a raft base (which seems necessary for smoothing out my prints.) The raft was a bit big on this one, and that took a lot of time. I printed at 0.15mm resolution, which I haven't used before, (previously I'd been printing at 0.1mm and the quality was great) in an effort to cut down on print time. Still, this took around 2 days of continuous printing to finish. I'd say somewhere between 24-38 hours.

The upper left printed at the same quality, but with much less support (10%) and much less raft. (I found the settings in my version of Cura to tweak the raft overlap and make it 0mm, since so little touches the buildplate -- or rather, the print is almost all overhangs but hte raft isn't needed where there won't be supports.) This printed fine, and will probably be easy to clean up -- the upper right piece is still waiting for me to finish pruning the supports off, and the 15% density of "line" supports are a bit too sturdy on this big print. With the speed, raft, and less-dense support settings, this print finished in about 20 hours.

Here's the two pieces on my desk, with only some of the upper right cleaned up:

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

caleb, 2018-04-30:
How did the keyboard turn out? I'm thinking about starting this project, and I've never 3D printed anything in my life, and I know that it would be cheaper and better to order from a professional, but it seems like a fun project to work towards.

mathias, 2018-04-30:
I have not printed the lower halves, as my 3D printer is broken for the time being. I do have switches, but have not worked on the circuitry (I was planning to wire point-to-point, as I've done on an Atreus keyboard build before the Atreus had a PCB.)

mathias, 2018-04-30:
It takes a very long time to print these, you may want to make sure you have a printer with a big enough build volume and that it is sufficiently fast. Some printers also can't run continuously for 20-30 hours for each build, like mine did -- they're just not that level of durability / reliability yet for some hobby-grade/DIY printers. YMMV, and good luck!

SteelBattalion, 2019-03-18:
I managed to print part of this out of pla with your recommendations. Some of the switch slots dead center didn't come out great but they should be use able. I'm planning on using polyurethane floor sealer to finish the case once its done printing. Just like you I had a component failure (thermistor) after the first print was done.

impaktor, 2019-03-19:
Would be interesting to hear thoughts on PLA _(what many use for their first print)_ vs. PETG vs. Nylon _(what adereth used)_. PLA has the downside of being brittle and very hard, which wouldn't absorb key presses the way one would like. Just considering the difference between aluminium vs. steel mounting plate for switches is quite noticeable, or so they say.

SteelBattalion, 2019-03-20:
So I managed to print the second piece and unfortunately it looks like it didn't print as well. There was poor layer adhesion around some points. I went ahead and gave both top pieces a layer of oil based polyurethane floor sealant anyway. I'll update tomorrow on how well it dried and if there was a noticeable improvement in rigidity.

SteelBattalion, 2019-03-20:
Polyurethane really helped the flex is nearly identical on both the good print and the one with layer separation after just one coat. I'm debating just sticking with one coat as I want to minimize the amount of hand filing and sanding I'll need to do in order to get the switches in place. Unfortunately my nozzle clogged some time this am in the middle of printing one of the bottom plates.

SteelBattalion, 2019-03-21:
> Would be interesting to hear thoughts on PLA _(what many use for their first print)_ vs. PETG vs. Nylon _(what adereth used)_. PLA has the downside of being brittle and very hard, which wouldn't absorb key presses the way one would like. Just considering the difference between aluminium vs. steel mounting plate for switches is quite noticeable, or so they say.

It's not that straightforward to compare against nylon. Since there are so many blends. I feel like we'd have to all agree on a set of commonly available types and each take responsibility for making a set...then meet at a convention to have a fair comparison.

SteelBattalion, 2019-04-04:
I finished the print but thought  i'd finish the build prior to adding more comments. First it might be worth adding a bit more suppoprt structures and deal with a more painful and tedious removal of the supports. Second for the less experienced at soldeing and 3d printing perhaps printing out an extended bottom case would be the way to go. The extended bottom case found here. https://www.thingiverse.com/thing:2436848  is what I ended up using and I quite like it.

SteelBattalion, 2020-10-18:
It's been over a year since I've printed my PLA keyboard and coated it in polyurethane. The keyboard has lived on my desk as a daily driver since then. I worked from home even before the lock down and it's held up well to typing. I don't use it for gaming so it doesn't get the type of button mashing abuse that some games require. Strictly as a tool for typing it's great. I also added six 3d printed buttons with micro switches to the base of my keyboard via double sided tape. Shortly after the initial print. Those buttons did not get a coat of polyurethane however as they get very little use they are also holding up just fine. I haven't dropped the halves nor had anything drop on them so I can't comment on drop test durability, but for typing my print is holding up very well.

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

Here is the model for the additional buttons I ended up using.

https://www.thingiverse.com/thing:1909644

SteelBattalion, 2020-11-01:
For those that might be curious my original print required some modification to both the print and the amoeba switches. Nothing a dremel tool and a soldering iron can't hash out.

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

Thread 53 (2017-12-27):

File not rendering in openSCAD

sevinty7, 2017-12-27:
Tested the same file from the things folder in openSCAD for windows and openSCAD for ubuntu.

Sits at  "Rendering Polygon Mesh using CGAL..." with 0/1000.

Please advise.

jaredjennings, 2017-12-27:
I saw that same sort of behavior, and chanced to leave it alone once. After like five minutes, it jumped to 400 and started counting. Have you tried leaving it to run for what seems to be an obscene amount of time?

If you don't want to run the Clojure code you can look at the rendered STL files; if you do run the code, you can turn the detail down to get an scad file that will render much faster.

Hope one of these helps; let me know.

sevinty7, 2017-12-27:
I'm planning on modifying the dactyl into a mini dactyl, so I'm using the clojure code to do that. I'm not sure if my laptop cpu just can't handle it, but i left it for 30 minutes with no success.

sevinty7, 2017-12-27:
I found the resolution setting and lowered it to 1. The inital render loads much more quickly, but when I try to press f6 so that I can export it as an STL file it does the same thing as before. Let me know if you guys have any ideas.

sevinty7, 2017-12-27:
Also this is what the inital render looks like when I download the openSCAD file from github.

https://i.imgur.com/sENxsUa.png

sevinty7, 2017-12-27:
@xcode-manolo I'm wanting to drop the amount of keys down to 32, only 2 thumb keys, and have it printable in a very small area 120mm^3.

xcode-manolo, 2017-12-27:
Ah, that's pretty small.  I had think only in removing numbers row.  That's
enough for me !

Thanks Derek !

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

jaredjennings, 2017-12-27:
i also don't have a large enough print volume for the whole thing, but i've set out to print a full-size keyboard in pieces and glue them together.

don't miss the lightcycle.clj; it might be more customizable for small keyboards.

as for the openscad screenshot, you have me baffled.

sevinty7, 2017-12-28:
I'm wondering if the render is just failing on my laptop core i5. I'll try it on something with more power at some point.

sevinty7, 2017-12-28:
Tried it on another computer. The preview showed up correctly, but the file did not render. I had left it for about 10 minutes.

orcinus, 2017-12-28:
Have the same issue. Sits at 127/1000 for ages (on a 3.6 GHz i7 core).
Tried leaving it for 20 minutes or so, hasn't moved.

Additionally, the pre-generated STLs are full of issues that cause various slicers to do weird things, even after running it through the Netfabb cloud service.

orcinus, 2017-12-28:
Found a solution. Well, kinda.
It renders fine in old OpenSCAD (2013-06 for example), except it takes about 2 hours or more.

Also doesn't have problems with self intersections and malformed polys either.

orcinus, 2017-12-29:
Scratch that last bit.
Some parts still have self intersections.

mcdviii, 2018-08-08:
So these are issues with OpenSCAD updates, specifically?

orcinus, 2018-08-08:
Yes and no.
The parametric geometry isn't too clean, and OpenSCAD is notoriously bad at doing booleans on more complex geometry, often crashing and resulting in self-intersections.

Since the algorithms changed from version to version, some have more luck with some edge cases, others with some others.

mcdviii, 2018-08-09:
Is there something more robust & stable that the project should be ported to?

jaredjennings, 2018-08-09:
Judging from the searching I've done every time I hit a roadblock, OpenSCAD and its underlying CGAL library are the only thing in this area with staying power. libfive looks interesting but has no hull function, upon which this code depends a lot.

orcinus, 2018-08-09:
Antimony is interesting, but i think it'd be a bit more of a pain to work in, as you'd need to write a ton of missing semi-primitive stuff first. Fun fact - the author of Antimony works at Formlabs.

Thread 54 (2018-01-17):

diode direction - Row / Columns Drive

funkrider, 2018-01-17:
In the README.org file the hand wiring pics as well as the text state "As you can see in these following pictures, I went for the “row-driven” setup (visible by the direction of the diodes, the black line being towards the key-switches). ". However it is my understanding that the black line as the cathode pointing towards the key would indicate the "Drive Columns" type setup would it not?
I think that the firmware has a simple config setting for either selection however that would need you to re-compile it for "Drive Columns" option. Am I correct or am I just a n00b out of his depth?

raychengy, 2018-04-01:
I believe you are right. If the black line on the diode is pointing towards the switch, its "Column" driven. The columns will be high and the rows that will be read as inputs.

If you're using the [benblazak/ergodox](https://github.com/benblazak/ergodox-firmware), you can switch the row/column driven option from the `/src/keyboard/ergodox/option.h` file.

raychengy, 2018-04-03:
Sorry, I'm wrong in my previous statement. I've wired the diodes such that the cathode is pointing towards the switch which is on an ergodox pcb board the circular solder pad, therefore its `DRIVE_ROWS`.

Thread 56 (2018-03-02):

Kailh is so hot right now, switches don't fit

joedevivo, 2018-03-02:
That's a Mod-H on the left and a Kailh Burnt Orange on the right.

There's a notch in the base of the standard MX switch that keeps the switch snug in the Dactyl case, but the Kailh switches are basically square.

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

FSund, 2018-03-14:
Can anyone confirm this? I was considering a Dactyl, but was planning on using Kailh BOX switches.

Do they not fit in the hole at all, or are they just not properly secured? One could always hot glue them in if they aren't properly held in place.

jaredjennings, 2018-03-14:
Judging from the picture, and from what I've seen of the switch hole design, the Kailh switches would likely not fit. This is quite important to me, because I've chosen and bought Kailh Brown switches for my build. Most simply, the pieces on the sides of the Dactyl switch hole that engage these Cherry-specific notches could be removed, and then glue may be required. I'd like to find a way that doesn't require glue. But in my modifications I haven't gotten to this problem yet. If no one has solved it by the time I arrive at it, I will, but I can't promise exactly when that will be.

chav02, 2018-03-15:
I've got a newly printed dactyl-manuform and kailh switches right here, and can confirm that their new design will not fit. :(

mcmadhatter, 2018-03-17:
I was able to get burnt orange box switches to fit in my dactyl-manuform, but they only fit in if the the little notches are set to deform the area around the led hole, I would still want to glue them in as well, just for extra hold.  Kailh Pro's also fitted.  (ignore the horrible yellow primer, I am in the priming/sanding phase)

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

FSund, 2018-03-27:
To make the Dactyl compatible with Kailh switches you can just edit [line 37 of src/dactyl_keyboard/dactyl.clj](https://github.com/adereth/dactyl-keyboard/blob/master/src/dactyl_keyboard/dactyl.clj#L37) and remove the `side-nub`. Replace

    plate-half (union top-wall left-wall (with-fn 100 side-nub))]

with

    plate-half (union top-wall left-wall)]

and you should be good to go.

I've made a fork of the [Dactyl-ManuForm](https://github.com/tshort/dactyl-keyboard) where I've implemented that change, as well as removed the teensy holder and wire posts, as well as some improvements suggested by [jmg123 over at Geekhack](https://geekhack.org/index.php?topic=88576.msg2578041#msg2578041). The diff can be seen [here](https://github.com/tshort/dactyl-keyboard/compare/master...FSund:master). This model should fit Kailh switches, and print faster.

TobiasWegener, 2018-04-14:
Ah, was planning to use Kailh Box Jade switches, or to they already have them...
Hm, I think I will go the manual way and remove the notch by hand may be with a sharp knife.

fi0, 2018-04-20:
It seems that oetumu cannot be used with side-nub. But gateron can be fitted.

Sylk, 2018-11-08:
@adereth please close this.

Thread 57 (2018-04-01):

Incorrect pinout with the Teensy & MCP diagram in guide/circuit-diagram.png

raychengy, 2018-04-01:
Based on the ErgoDox EZ [schematics](https://github.com/ErgoDox-EZ/docs/blob/master/ErgoDox%20EZ%20Schematic.pdf), pin `INTA` on the MCP23018 is not used. I think there is a simple mistake on the [guide/circuit-diagram.png](https://github.com/adereth/dactyl-keyboard/blob/master/guide/circuit-diagram.png) file. Could you tell me what program was used to make this diagram? Col-5 to Col-0 needs to be shifted up a input on the MCP23018 schematic.

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

Mese96, 2018-04-01:
These pull request would fix this:
https://github.com/adereth/dactyl-keyboard/pull/51

raychengy, 2018-04-03:
Awesome! I'll close out this issue.

nomath4u, 2019-02-26:
This never got pulled in.

Marcus-Zhu, 2019-07-26:
Please consider pulling this fix.

nomath4u, 2019-10-26:
Just started making my second one and made the same mistake again 😭

Closed 2018-04-03.

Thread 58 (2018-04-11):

Pull parameters out of dactyl.clj into their own params file

rmwphd, 2018-04-11:
The parameters of interest for customizing the shape of the keyboard to suit a given user are not well-exposed to the user editing the code. It would be nice to create a user parameters file which contains all of the parameter vars and then import that file into the dactyl.clj file.

I guess from a basic search that, in Clojure, the correct thing to do would be to `use` or `require` the a new namespace called, e.g., params from a params.clj file in src/params.

I'd do it myself, but I can't easily tell which parameters ought to be factored out.  If someone can explain to me what variables decide, e.g.,  the angle of tenting or the curvature of each finger column, I'll be glad to write this up and put in a pull request.

jaredjennings, 2018-04-12:
The tenting angle is hard-coded: it is the `(/ π 12)` toward the end of `key-place`.

The curvatures across the keyboard and from top to bottom are defined as α and β. I don't know how to express what these do: I just changed them and re-rendered a lot of times, and when they are bigger the keyboard is curved more tightly. This iterative exploration goes a lot faster if you comment out the case in the `write-scad` calls at the bottom.

nickcoutsos, 2018-05-03:
Yeah, alpha and beta define the angle between rows and columns. What really makes customization awkward is that the radii of the curves are defined in terms of those angles as well as keycap dimensions. Documentation would be fantastic for people making variations that are still "correct" implementations of the ergonomics but I don't know who is interested in maintaining anything like that.

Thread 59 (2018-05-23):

Sizes of thumb cluster LightCycle's keycaps ?

xcode-manolo, 2018-05-23:
I'm going to make a Dactyl LightCycle with Matias switches and I don't find anywhere what thumb cluster keycaps sizes are.  And there are very few offers for buying ALPS keycaps on the web.

Does anyone can tell me if they are 2u, 1.5u, 1.25u, or something else ?  I want to find them and order them before build the keyboard.

jaredjennings, 2018-05-23:
```
(defn thumb-layout [shape]
  (union
   (thumb-place 0 -1/2 (union shape (extended-plates 2)))

   (thumb-place 1 7/8 (union shape (extended-plates 1.25)))
   (thumb-place 1 -5/8 (union shape (extended-plates 1.75)))

   (thumb-place 2 -3/4 (union shape (extended-plates 1.5)))
   (thumb-place 2 3/4 (union shape (extended-plates 1.5)))
   ))
```

This says to me that you have one 2u key, one 1.25u key, one 1.75u key, and two 1.5u keys. After an image search, I'm confident I've read the code above correctly.

Good luck with the Alps keycaps. I'd like to see how things turn out for you! Maybe post on Geekhack or r/mechanicalkeyboards?

Closed 2018-05-23.

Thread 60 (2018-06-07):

Bad Model?

jrozner, 2018-06-07:
I'm working on printing the dactyl case pieces at home on my Prusa Mk3 using Slic3r Prusa edition to slice the file. I'm seeing some weird behavior in the left bottom with teensy when I slice and print it. It looks like there might be some bad geometry that's causing it to be seen as two pieces rather than one and basically builds supports between the two which snap apart when I rip off the supports. Is this intended and if not is there an issue with the model? In the screenshot below the yellow is the model being printed and the green are supports. You can see in the top right corner there is a section of supports that cuts through it.

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

When I import the stl file into slic3er it reports that there were 12 errors that were auto repaired but I'm not sure how to see what those are. Has anyone else experienced this?

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

mcdviii, 2018-08-08:
I am experiencing something similar in roughly the same area on the nonstandard models under /things. My problems are seemingly missing mesh. I even built from OpenSCAD source.

I'm away from computer right now. I can post version numbers later.

jrozner, 2018-08-09:
I actually tried a few prints flipping it 180 so that the outer shell would have a better finish. I had issues getting a successful print with that orientation due to the minimal surface area touching the build platform. The corners came loose and destroyed the print.

RedWagon, 2018-11-07:
I'm having issues with the left side with teensy as well.  I compiled my own STL and repaired it in slic3r and got something that looks manifold in the preview but I'm getting the issue where supports just cut through the model.

Printing discussion:
This was printed upside down.  To fix the corners I set enforce supports for the first 10 layers.
https://www.thingiverse.com/make:561129

jaredjennings, 2020-10-19:
https://www.reddit.com/r/openscad/comments/gmpnjj/question_is_anyone_else_experiencing_issues_when/

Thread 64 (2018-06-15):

Mini Dactyl

xcode-manolo, 2018-06-15:
Hi, guys !!!

Does anyone know about a Dactyl with 3x5 +5 keys ?

It would be a kinda of a MiniDactyl.  A minimal version.

Have a great day, you dudes !!!

;-)

szos, 2018-08-24:
the dactyl manuform has a 3x5 +2 under row 2 and 3. the thumbs may turn you off though. you can also grab the clojure environment and define your own.

xcode-manolo, 2018-08-24:
Yes, I know that model.  But those two extra keys... I can’t find sense for them.
And I know, the clojure sources are open source, but the problem is the omnipresent problem: time.
It doesn’t worth to me learning clojure for modify sources.
I was looking for a model as I dream, I know, it’s very difficult that exists, but it isn’t impossible.  That’s because I asked the community about the existence of that model.

But at the end, I have to finish typing on a Mini Dactyl.  If it doesn’ exist, I will have to give in and create it, I’m sure.

Thanks anyway, dude !!!

;-)

manolodeinternet, 2019-06-25:
Hi guys and @szos  !

Mini Dactyl exists !!!

[Click here for Reddit post](https://bit.ly/2wS1JOM)

I finally got it !

;-)

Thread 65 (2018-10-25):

Keyboard with return row

jgwinner, 2018-10-25:
I've been using a keyboard for MANY years.

I love the parameterized design files; I'm wondering if I could use these to build a keyboard with a return row on the right hand side.

I realize there's better ways to do it, but I use a laptop keyboard fairly often, on the go, so I can't drag the keyboard around everywhere. I'm just sort of used to it.

Is that possible or would it make the two sides too big?

I have to admit I can just try it, but thought I would float this out here first.

I know I should use my thumb :) but I know that pinky will occasionally reach out - especially for the backslash.

Also - it would be great if on the front page there was a diagram showing what key combinations there are; as a n00b to these kinds of keyboards it's a little confusing.

Thank you for listening,

== John ==

jaredjennings, 2018-10-26:
John, you might want to see pull request #4, which someone was talking about the other day. It has an extra column.

As for choices - the Dactyl is defined using code. I tried to make my fork have code and separate configuration, so the choices would be obvious, easy to make, and easy to "deploy," i.e. make pictures and STLs for, or make [lists of](https://www.xkcd.com/974/). I haven't even accomplished that goal for the choices I've added in my fork, much less the 90 other forks, much less whatever branches or pull requests they may have.

I started once to try to make a time-lapse video of the changes I've made in my own fork. I made a script that goes to each revision, runs the Clojure code, and runs OpenSCAD on certain of the resulting scad files. The next step was to render those into pictures, but I haven't gotten there yet. Some generalization of this is probably how to catalog the variants, rather than attempting to harmonize codebases made by people whose incentives are toward divergence not convergence.

jgwinner, 2018-10-26:
Thank you!

I had seen that one, I liked the 'drop to the floor' housing too, and the thread inserts.

I guess as I'm pretty new to DIY keyboards, I'm also sort of asking "Should I" :)  I haven't seen any of these with a traditional return key, or ]'s, etc.

Anyway, thanks for the response ... it's this or a Kinesis Pro :)

I'll close the issue (it's more of a discussion than an issue). I'll play around with the CAD files.

Love parameterized code; I was a user of POVRay for exactly that reason a long time ago.

== John ==

jotomo, 2018-10-26:
Hi John, I'm also starting my journey into DIY keyboards. I'm currently using a TEK (https://www.trulyergonomic.com/store/truly-ergonomic-mechanical-keyboard-soft-tactile-kailh-cherry-mx-compatible-brown-keyswitches-229-english which has enter and backspace in the middle) at my desk and a Thinkpad on the go (and an MS Sculpt ergo keyboard at work, for the moment).
Interestingly, my hands / muscle memory seem to recognize what's under them and just work (after 2-3 of initial learning where I hit the wrong side). Pressing enter/backspace with thumb/index on one keyboard or using the pinky on the other just works like touch typing any old character key. This also works with symbols that moved from left hand to right hand (=+-_), with only a few errors. So that seems to be a simple matter of learning, at least for me.
Therefore I'm optimistic this will extend to the layers concept, which I find intriguing: rather than moving your hands over to other keys (or stretching them to get there), move the keys under your hand (or rather their assigned symbol) by pressing a modifier. E.g. when completing a method name, rather than to have to move the right hand down over the cursor keys, your left hand presses a layer modifier to move the cursor keys under your right hand, which can stay in place.
I'm also using vim, which has the navigation layer, which also works, making me more confident using and adjusting to a dactyl keyboard will work for, while still being able to use a normal keyboard on a notebook. HTH.

jgwinner, 2018-10-26:
Hi Jotomo!

I hear you on the layers, but I frequently use CAD tools that tie one hand (at least) into the mouse to do sensitive movements, then you want to hit an FKey. That's why the top row of F keys (in row layout) are pretty attractive to me. I get you on mainly using Linux.

This was the keyboard I have: The freestyle 2: https://www.kinesis-ergo.com/shop/freestyle2-for-pc-us/

I wore the one at work AND the one at home out - the little nibs on he F and J keys are shot, and I frequetnly ytor ygetibh ygubh, (I think that was 'the wrong thing' shifted a letter to the center, LOL).

So, I figured if I'll replace it, I'm either upgrading to: https://www.kinesis-ergo.com/shop/freestyle-pro/ but thought I'd check into the Ergo DIY keyboards. Sounds like fun projects.

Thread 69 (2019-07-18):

Dimensions Request

ifohancroft, 2019-07-18:
What are the degrees of the curve between the different keys? Also, is the spacing between the switches 19.05mm or 19mm? Does the current design fit a sculpted SA profile or do all keys need to be R3?

Closed 2019-08-29.

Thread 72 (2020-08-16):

Automatic PCB generation?

Supermagnum, 2020-08-16:
Since the position of the holes for the switches is known, there should be possible to add a utility that places the footprints of the switches according to the geometric layout of the keyboard halves.
Placement on the pins for ALPS switches:
https://matias.ca/switches/click/blueprints/3.jpg
Cherry switches:
https://www.cherrymx.de/en/dev.html

Hybrid footprints for Kicad ( he should have used a oval hole, its easy to spot where )
https://github.com/ai03-2725/MX_Alps_Hybrid

Kicad has a python API:
https://docs.kicad-pcb.org/master/en/plugins/plugins.html

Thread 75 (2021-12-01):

Static discharge

SteelBattalion, 2021-12-01:
Over the time I've owned my dactyl I've noticed occasionally the led's will flash and multiple keys will become active. This can be a problem as it activates several predefined os keyboard shortcuts. I noticed that when this occurs on re plug in of the keyboard sometimes a few keys will remain in an always active state on the left half/non-arduino half. Some searches on line produced similar issues with the ergodox split keyboards. Static build up resulting in unresponsiveness or random keyboard behavior and potentially mcu death. I'm testing adding a diode to the mcp's ground connection. This should prevent the left hand portion lock ups I'm experiencing assuming that static is traveling through ground into the mcp. Has anyone else experience this behavior?

SteelBattalion, 2021-12-02:
Adding a diode to the mcp ground helped keep the left hand side from becoming the problem, however the right hand side was still having issues. as I'd made a cable from two different pieces I had access to the ground from the teensy to the pc. I installed a diode in there as well. Let's hope this works.

SteelBattalion, 2021-12-02:
The diodes appear to have helped. I can still see the static charge happen as whenever it did happen I would notice my indicator lights would flash, but now I don't get the key activation as it can only go in one direction I guess. I was able to replicate the issue by touching another device accidentally (small transistor) and then grounding myself on the pc chasis. At those levels it appears to have exhibited the same behavior as pre diode install.

SteelBattalion, 2021-12-06:
Meh still doing it seems a bit more resistant. Sometimes only the led's flash, other times it still sends key commands.

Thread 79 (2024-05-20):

Keyboard not working / Diodes

mx-ws, 2024-05-20:
Hi,
first of all, thanks for all the work!
I was following the guide and finally finished wiring everything together. I then flashed the firmware using https://github.com/flyck/ergodox-firmware as referenced in the guide. But the keyboard does not seem to work. I am not an expert in either soldering or teensy stuff, so if it looks like I'm just missing same basics, feel free to just point me to the right resources. I also realize this project should not be viewed as active, I just did not know a better place to ask. Here are some things I can say:

1. I noticed I am not using the diodes mentioned here: https://github.com/adereth/dactyl-keyboard/issues/67. A lot of time has passed since I bought the diodes I am using, so I don't remember my reasons. Could that be the problem and might it be worth a try, to buy the other diodes and replace them?
2. I successfully flashed other programs to the teensy, your usual hello world programs, from arduino as well as an example c program. Something curious I noticed is that the internal led will only light up if I disconnect PD6 (I only noticed because I did not solder this one well :D) Is that expected or could that point to the underlying problem?
3. I am able to light the three external leds, at least with arduino.

Any help appreciated =)

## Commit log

2015-03-13 Adding pregenerated thing files
    [alternathumb.scad, key.scad, key.stl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]
2015-03-13 Adding one piece left hand
    [one-piece-left.stl]
2015-12-02 New model!
    [alternathumb.scad, key.scad, key.stl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]
2015-12-04 Finally sharing new model
    [dactyl-bottom-left.stl, dactyl-bottom-right.stl]
2015-12-04 Including PCBs and updating README
2016-09-06 Added the wiring section
2016-10-10 Update link to README.org for wiring
2017-03-08 Adding version with Teensy on left side
    [dactyl-bottom-left-with-teensy.stl]
2017-03-10 Quick and dirtly wrist rest
    [wrist.scad, wrist.stl]
2017-03-10 Regenerated wrist
    [wrist.stl]
2017-04-23 LightCycle with Cherry holes
    [lightcycle-cherry-bottom-left.stl, lightcycle-cherry-bottom-right.stl]
2017-04-23 Fixing left side with teensy, accidentally had ALPS switches
    [dactyl-bottom-left-with-teensy.stl]
2017-05-19 Fixed TRRS cable name typo in README
    The word TRRS was misspelled as TTRS, making it difficult to identify this part.
2017-06-08 [WIP] QMK Guide
    [digikey-shopping-cart.csv]
2017-06-16 Fix MCP columns in wiring diagram
2017-06-21 Remove columns 6 and 7
    I _think_ these columns came in from the ergodox circuit diagram.
    Compared to the dactyl, the ergodox has one extra column per hand (the
    three-key column at the middle).
2017-06-21 A bit more info about pull-up resistors
2017-06-25 The pullups go to the I/O expander, not switches!
